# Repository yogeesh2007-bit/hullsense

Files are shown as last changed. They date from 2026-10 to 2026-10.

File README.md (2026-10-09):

# HULLSENSE

**Real-time strike localisation and breach sizing for crewed-module walls.**
SEDHACKS '26 · Track 03 Space Instrumentation · Hardware
Team **BYTEMELATER** · Team lead **Yogeeshwaran C** · Rajalakshmi Engineering College, Chennai

When debris hits a space-station wall, the crew needs three answers fast: *where did it hit, did it breach, and how long do we have?* Today those answers can take days. On the ISS in 2020 a leak was finally found with floating tea leaves. HULLSENSE answers all three in seconds with five ₹20 piezo discs, one pressure sensor and an ESP32, for about ₹1,479.

- 📄 **Build brief and documentation:** https://yogeesh2007-bit.github.io/hullsense/
- 🖥️ **Live dashboard** (simulation mode works without hardware): https://yogeesh2007-bit.github.io/hullsense/dashboard/
- 🔧 **Firmware:** [`firmware/hullsense_node`](firmware/hullsense_node)
- 📐 **CAD model:** [`hardware/cad`](hardware/cad) (STEP assembly, STL parts, dimensioned drawing); interactive viewer at `docs/cad/`

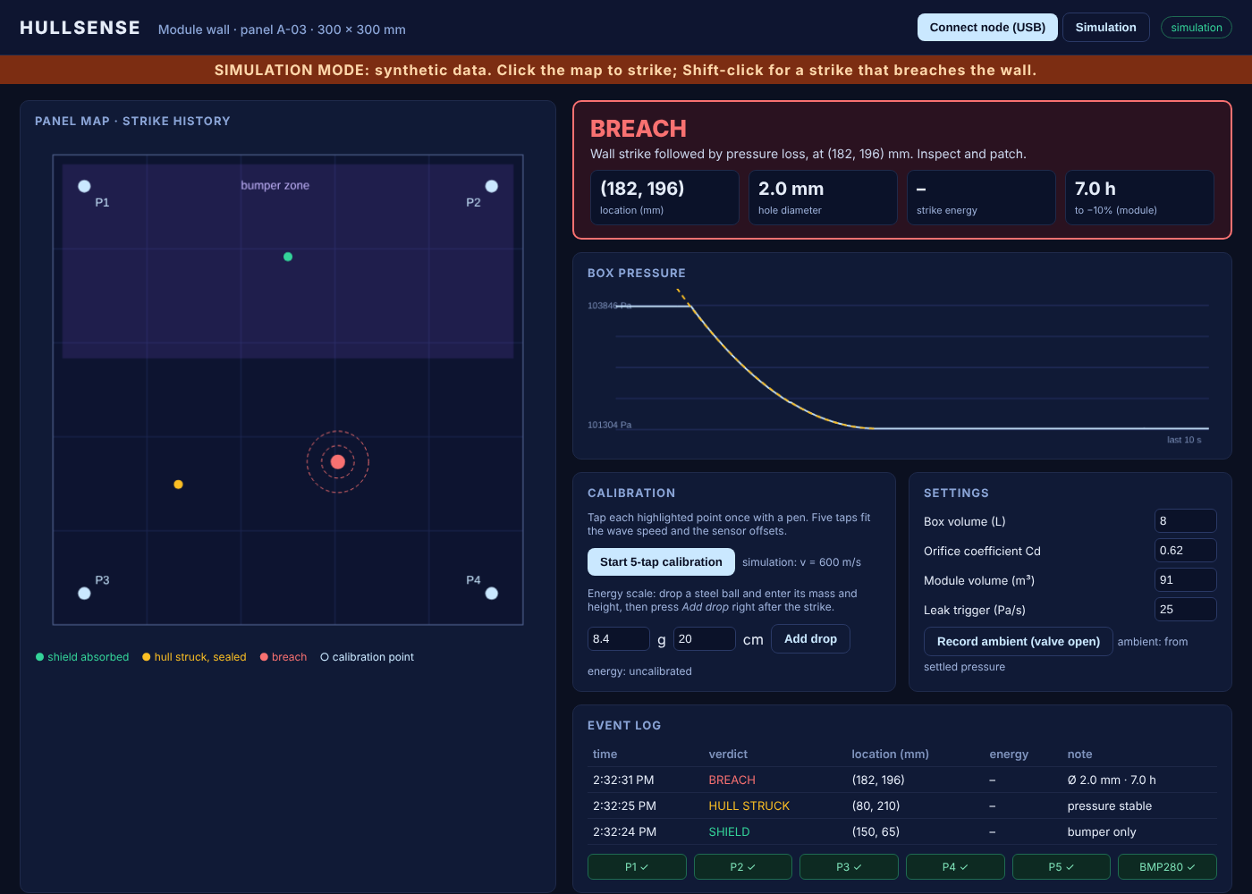
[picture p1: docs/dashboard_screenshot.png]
Dashboard in simulation mode


## How it works

| Step | What happens | Where |
|---|---|---|
| 1 · Strike | A strike sends a ripple through the 1 mm aluminium wall. | test rig |
| 2 · Timing | Four corner piezos and one bumper piezo feed band-pass filters and LM339 comparators; the ESP32's MCPWM capture hardware timestamps every edge at 12.5 ns. | `firmware/` |
| 3 · Locate | The dashboard finds the point that best explains the four arrival times (least squares, after a 5-tap calibration of wave speed and sensor offsets). | `docs/dashboard/solver.js` |
| 4 · Triage | Bumper sensor first → **shield absorbed**. Wall strike with steady pressure → **hull struck, sealed**. | `solver.js · triage()` |
| 5 · Size | If box pressure falls after a wall strike, the decay curve is fitted with the orifice equation to get the hole diameter, then scaled to a station-class module with a choked-flow model → **breach: location, Ø, minutes left**. | `solver.js · fitBreach(), flightMinutes()` |

## Repository layout

```
firmware/hullsense_node/   ESP32 firmware (Arduino-ESP32 3.x)
docs/                      GitHub Pages site: build brief + live dashboard
docs/dashboard/            Web Serial dashboard (index.html, app.js, solver.js)
hardware/                  BOM, wiring, one-channel schematic
hardware/cad/              Parametric CadQuery model: STEP, GLB, STL, A3 drawing, renders
analysis/                  Python model: decay curves, hole sizing, flight scaling
tests/                     Solver tests on simulated strikes (node tests/solver.test.js)
```

## Hardware

See [`hardware/BOM.csv`](hardware/BOM.csv) and [`hardware/wiring.md`](hardware/wiring.md).

| Signal | ESP32 pin |
|---|---|
| P1 wall (20, 20) mm | GPIO 34 |
| P2 wall (280, 20) mm | GPIO 35 |
| P3 wall (20, 280) mm | GPIO 32 |
| P4 wall (280, 280) mm | GPIO 33 |
| P5 bumper | GPIO 25 |
| Timer sync (internal loop-back, leave unconnected) | GPIO 26 |
| BMP280 SDA / SCL | GPIO 21 / 22 |

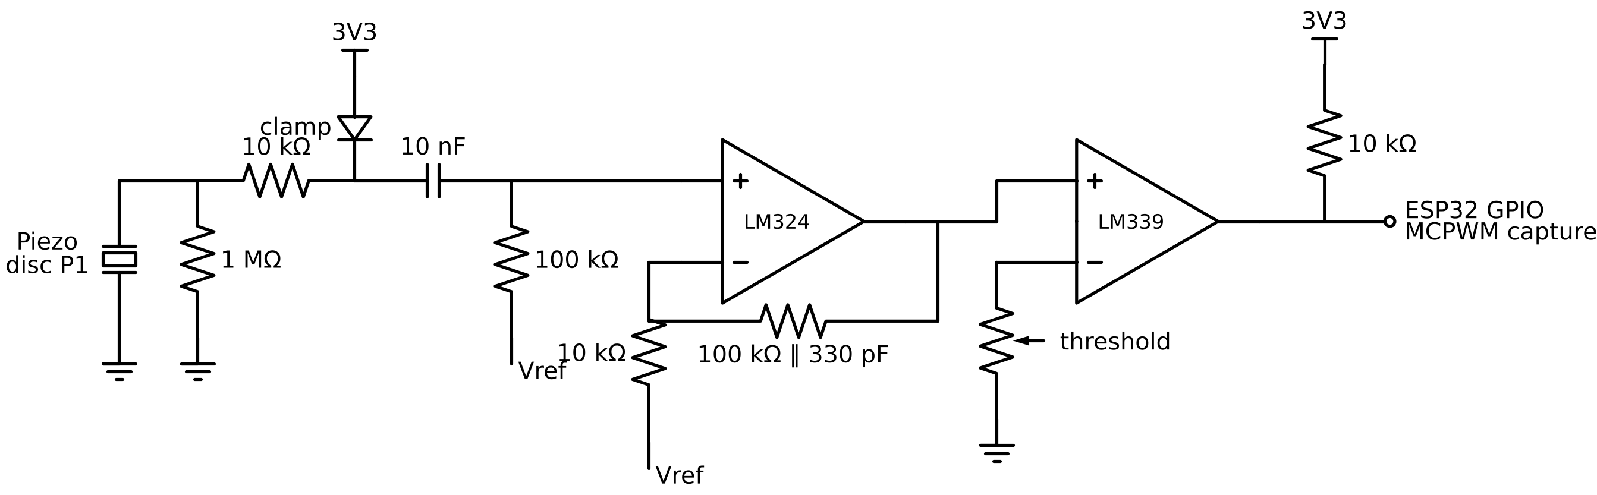
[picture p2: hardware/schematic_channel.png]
One channel


## CAD model

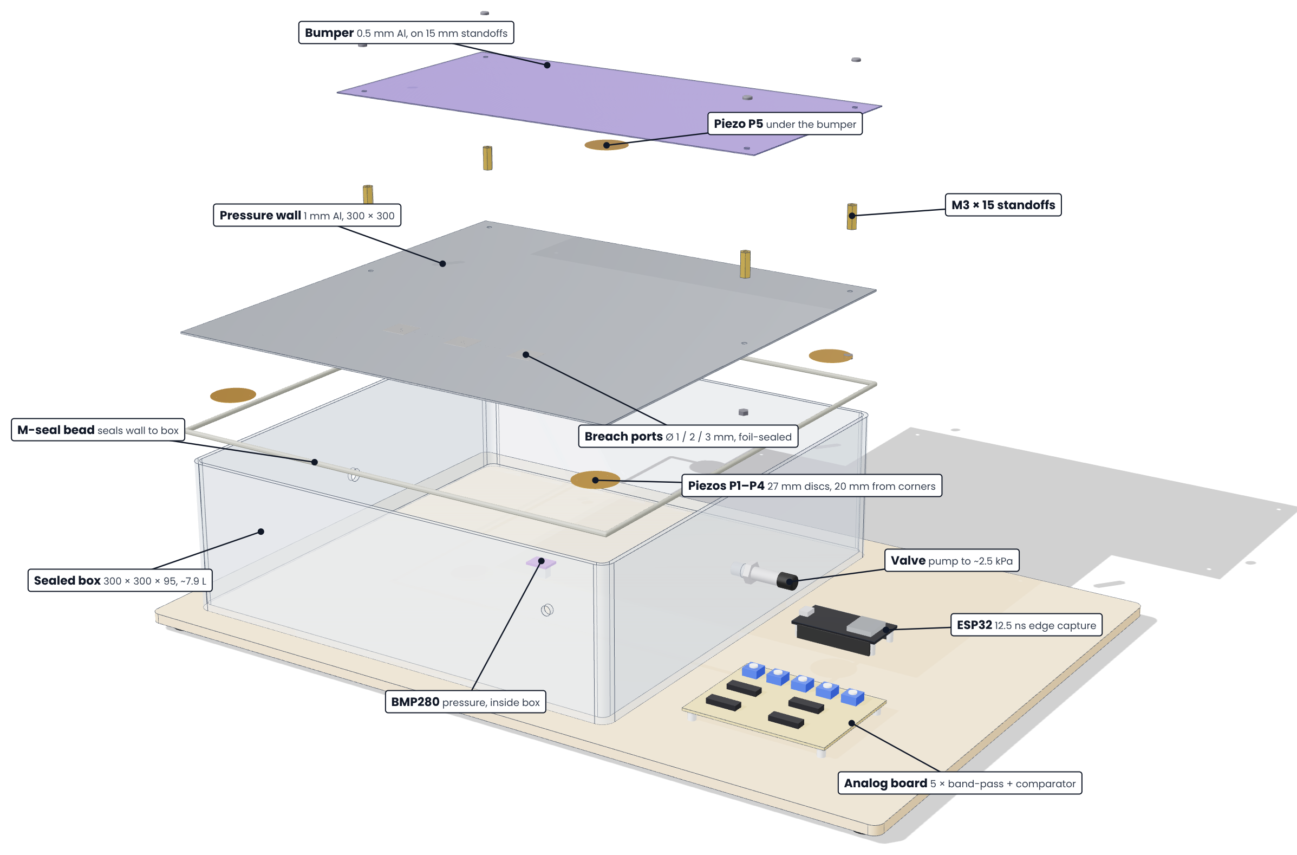
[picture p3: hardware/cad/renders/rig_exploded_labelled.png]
Exploded CAD view


`hardware/cad/hullsense_rig.py` is a parametric CadQuery model of the whole rig. Every dimension lives at the top of the file, and the sensor positions match `solver.js`. Run `pip install cadquery && python3 hardware/cad/hullsense_rig.py && python3 hardware/cad/drawing.py` to regenerate:

| File | What it is |
|---|---|
| `hullsense_rig.step` | Coloured assembly for Fusion 360, SolidWorks, FreeCAD or Onshape |
| `hullsense_rig.glb`, `hullsense_rig_exploded.glb` | Web and Blender versions (used by the viewer in `docs/cad/`) |
| `stl/*.stl` | Wall plate, bumper, box, standoff and base board as separate parts |
| `hullsense_rig_drawing.pdf` | A3 workshop drawing: wall layout, section A–A and parts list |

## Build and flash the firmware

1. Arduino IDE 2.x → Boards Manager → install **esp32 by Espressif, version 3.x** (tested with 3.0.7).
2. Library Manager → install **Adafruit BMP280 Library**.
3. Open `firmware/hullsense_node/hullsense_node.ino`, board **ESP32 Dev Module**, upload.
4. Serial output is JSON lines at 921600 baud (`evt`, `p`, `hb`).

Build check: compiles for ESP32 Dev Module with Arduino-ESP32 3.0.7, using 317 KB flash (24%) and 21 KB RAM (6%).

## Run the dashboard

Open https://yogeesh2007-bit.github.io/hullsense/dashboard/ in Chrome or Edge.

- **With the node:** *Connect node (USB)* → *Start 5-tap calibration* → tap the five highlighted points → strike the panel.
- **Without hardware:** *Simulation* → click the map to strike, Shift-click for a strike that breaches the wall.

## Tests

```
node tests/solver.test.js
python3 analysis/hullsense_model.py
```

The solver test recovers wave speed and sensor offsets from 5 simulated taps, locates 25 simulated strikes, and sizes simulated 1, 2 and 3 mm breaches. These are simulations; bench numbers from the real rig go in `analysis/results.md` once measured.

## Status and honest limits

- Lab strikes (dropped balls, punches), not 7 km/s hypervelocity impacts. The demo proves the locate → triage → size pipeline.
- Location accuracy target: median ≤ 2.5 cm on a 25-point grid. Hole-size target: within ±15%. Both are targets until the bench tests are logged.
- Prices for the ESP32, piezo and BMP280 were checked online in October 2026; the rest are estimates.

## Licence

MIT. NASA photographs used in the documentation are public domain.

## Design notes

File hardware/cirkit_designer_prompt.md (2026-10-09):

# Cirkit Designer prompt: HULLSENSE sensor node

Paste the block below into Cirkit Designer's AI prompt. It matches `hardware/wiring.md` and the firmware pin map in `firmware/hullsense_node/config.h`.

```
Design the full wiring diagram for "HULLSENSE", an ESP32 impact-localisation and pressure-monitoring node. Use these exact parts, nets and pins.

PARTS
- 1x ESP32 DevKit V1 (30-pin, ESP-WROOM-32), powered from USB
- 5x piezo disc 27 mm (2-wire): P1, P2, P3, P4 (on the wall) and P5 (on the bumper)
- 2x LM324 quad op-amp (U1, U2), DIP-14
- 2x LM339 quad comparator (U3, U4), DIP-14
- 1x BMP280 pressure sensor module (GY-BMP280, I2C)
- 5x 10 kΩ trimpot (RV1-RV5) for the comparator thresholds
- Per channel (x5): 1 MΩ, 10 kΩ, 100 kΩ, 100 kΩ, 10 kΩ, 10 kΩ resistors; 10 nF and 330 pF capacitors; 2x 1N4148 diodes
- Reference: 2x 10 kΩ divider + 10 µF capacitor
- Decoupling: 4x 100 nF (one per IC)

POWER NETS
- 5V net = ESP32 VIN pin (5 V from USB). It powers U1-U4: LM324 pin 4 = VCC, pin 11 = GND; LM339 pin 3 = VCC, pin 12 = GND.
- 3V3 net = ESP32 3V3 pin. It powers the BMP280, the comparator pull-ups, the clamp diodes and the trimpots.
- VREF net = 1.65 V: a 10 kΩ from 3V3 to VREF, a 10 kΩ from VREF to GND, and 10 µF from VREF to GND.
- All grounds are common.

ONE ANALOG CHANNEL (draw 5 identical copies, CH1-CH5)
1. Piezo (+) goes to node IN; piezo (-) to GND. Add 1 MΩ from IN to GND (bleed).
2. 10 kΩ series resistor from IN to node CLAMP. Add a 1N4148 from CLAMP to 3V3 (cathode at 3V3) and a 1N4148 from GND to CLAMP (cathode at CLAMP).
3. A 10 nF coupling capacitor from CLAMP to node B. Add 100 kΩ from node B to VREF.
4. Op-amp, non-inverting amplifier with gain about 11: (+) input = node B. Feedback from the output to the (-) input is 100 kΩ in parallel with 330 pF. Add 10 kΩ from the (-) input to VREF.
5. Comparator: (+) input = op-amp output. (-) input = trimpot wiper (trimpot ends to 3V3 and GND).
6. The comparator output is open-collector: add a 10 kΩ pull-up to 3V3 (NOT 5V). This node is the channel output to the ESP32.

CHANNEL ALLOCATION
- Op-amps: U1A -> CH1, U1B -> CH2, U1C -> CH3, U1D -> CH4, U2A -> CH5. On the unused U2B-U2D, tie (+) to VREF and the output to (-).
- Comparators: U3A -> CH1, U3B -> CH2, U3C -> CH3, U3D -> CH4, U4A -> CH5. On the unused U4B-U4D, tie both inputs to GND.

ESP32 CONNECTIONS
- CH1 (P1, wall corner 20,20 mm) -> GPIO34
- CH2 (P2, wall corner 280,20 mm) -> GPIO35
- CH3 (P3, wall corner 20,280 mm) -> GPIO32
- CH4 (P4, wall corner 280,280 mm) -> GPIO33
- CH5 (P5, bumper) -> GPIO25
- GPIO26 = timer sync loop-back used inside the firmware: leave it unconnected.
- BMP280: VCC -> 3V3, GND -> GND, SCL -> GPIO22, SDA -> GPIO21, CSB -> 3V3 (selects I2C), SDO -> GND (address 0x76).

LAYOUT AND LABELS
- Place the ESP32 in the centre, the five channels in a column on the left, and the BMP280 on the right.
- Label every net: 5V, 3V3, VREF, GND, CH1_OUT ... CH5_OUT, SDA, SCL.
- Label each piezo P1-P5 and each trimpot "threshold CHn".
- Colour the wires: red 5V, orange 3V3, black GND, blue signals, green I2C.
```

## If the tool is missing a part

- **No LM339:** use LM393 (dual comparator, same open-collector output). You will need 3 chips for 5 channels.
- **No piezo disc:** use "piezo buzzer (passive)" or a generic 2-pin sensor, and label it "27 mm piezo disc".
- **Circuit too large for one prompt:** first ask for one channel plus the ESP32 and the BMP280, then say "duplicate the channel four more times to GPIO35, 32, 33 and 25".

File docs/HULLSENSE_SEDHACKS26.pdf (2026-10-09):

# SEDHACKS'26

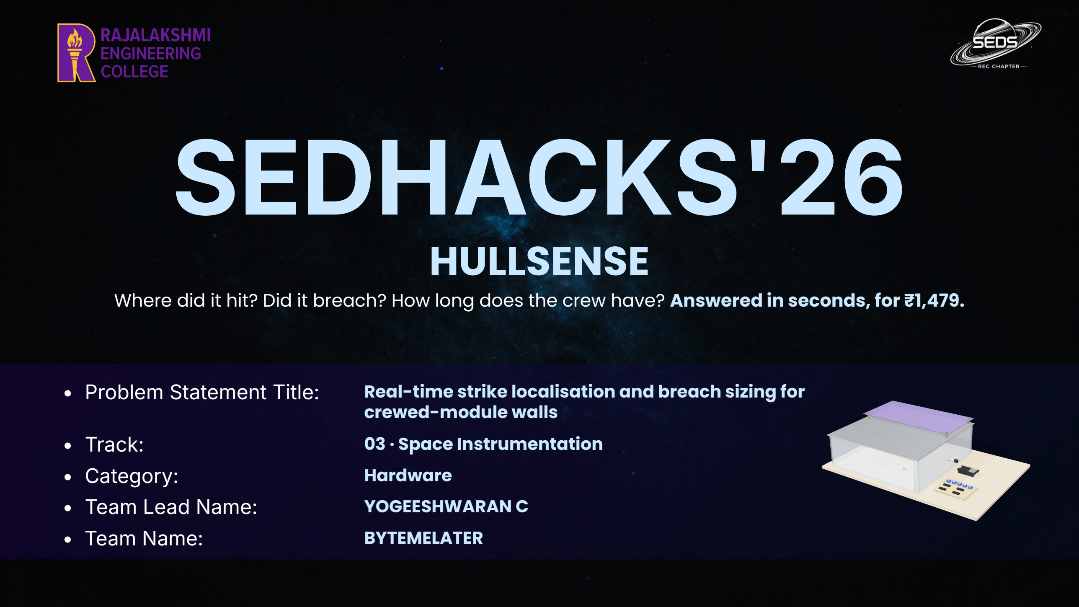
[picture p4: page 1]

## - Problem Statement Title:

## - Track:

## - Team Name:

## - Category: - Team Lead Name:

# Real-time strike localisation and breach sizing for crewed-module walls 03 · Space Instrumentation

# BYTEMELATER

# Hardware YOGEESHWARAN C

# HULLSENSE

Where did it hit? Did it breach? How long does the crew have? Answered in seconds, for ₹1,479.

# PROPOSED SOLUTION

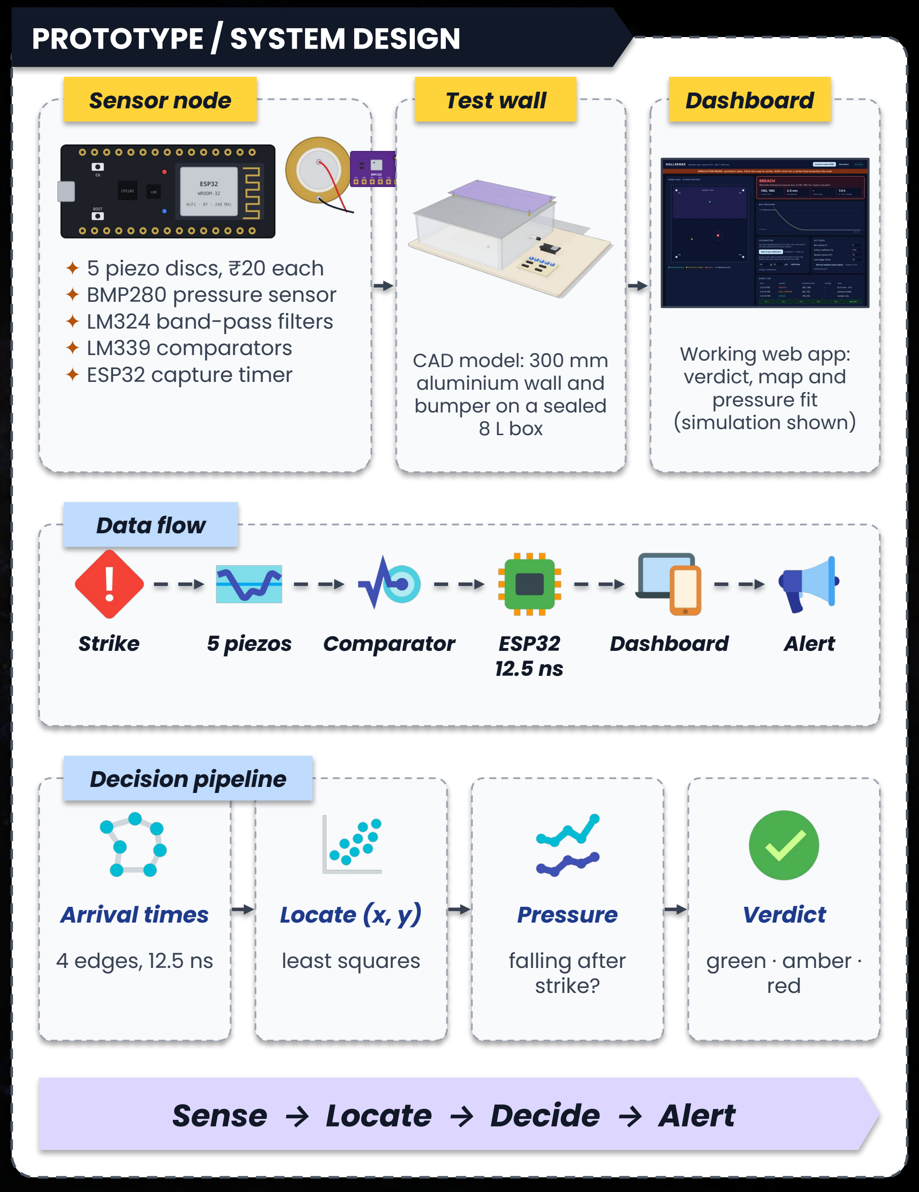
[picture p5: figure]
PROTOTYPE / SYSTEM DESIGN; Sensor node; ✦ 5 piezo discs, ₹20 each ✦ BMP280 pressure sensor ✦ LM324 band-pass filters ✦ LM339 comparators ✦ ESP32 capture timer; Test wall; CAD model: 300 mm aluminium wall and bumper on a sealed 8 L box; Dashboard; Working web app: verdict, map and pressure fit (simulation shown); Data flow; Strike; 5 piezos Comparator; ESP32; Alert; Arrival times 4 edges, 12.5 ns; Locate (x, y) least squares; Pressure falling after strike?; Verdict green · amber · red; Decision pipeline; Sense Locate Decide Alert →
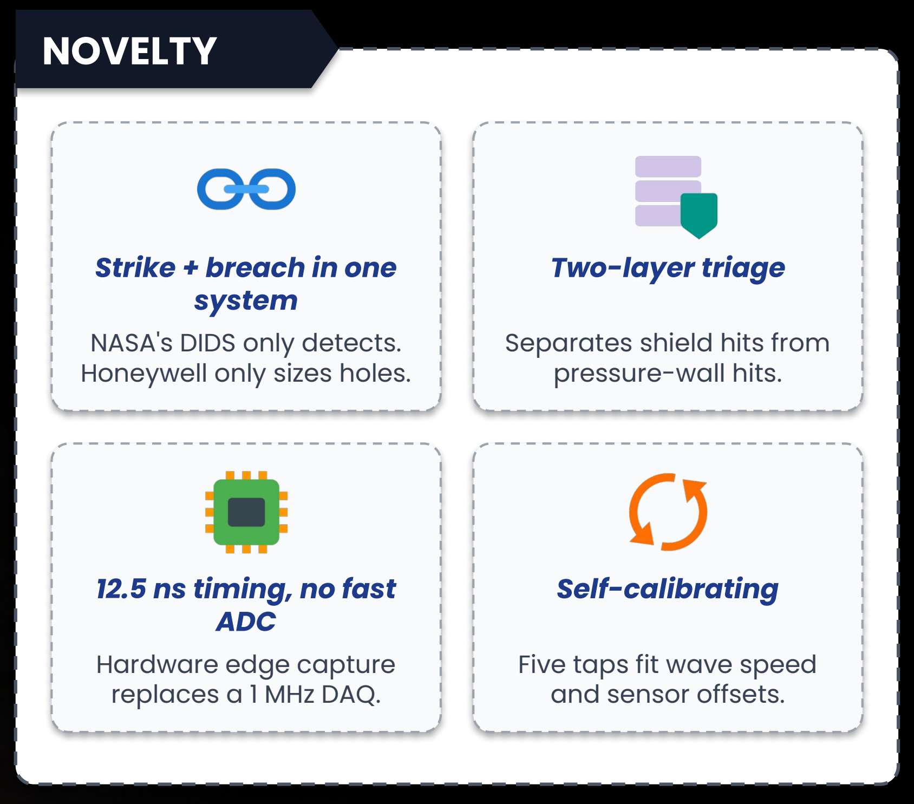
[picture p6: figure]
NOVELTY; Strike + breach in one system NASA's DIDS only detects. Honeywell only sizes holes.; Two-layer triage; Separates shield hits from pressure-wall hits.; 12.5 ns timing, no fast ADC Hardware edge capture replaces a 1 MHz DAQ.; Self-calibrating; Five taps fit wave speed and sensor offsets.

## THE SOLUTION

HULLSENSE is a ₹1,479 sensor skin for a crewed-module wall. When something strikes it, the system tells the crew where it hit, whether the hull was breached, how big the hole is and how long they have, within seconds.

### Locate the strike

Four corner sensors time the ripple a strike sends through the wall. The arrival-time differences give the (x, y) point.

### Shield vs hull

A fifth sensor on the outer bumper tells a harmless shield hit apart from a strike on the pressure wall.

### Size the breach

If box pressure falls after a wall strike, the decay curve gives the hole diameter and the minutes left.

### Alert in seconds

The dashboard shows the verdict, the location and the pressure fit as soon as the strike lands.

A real strike: micrometeoroid hole in ISS insulation (NASA, 2007)

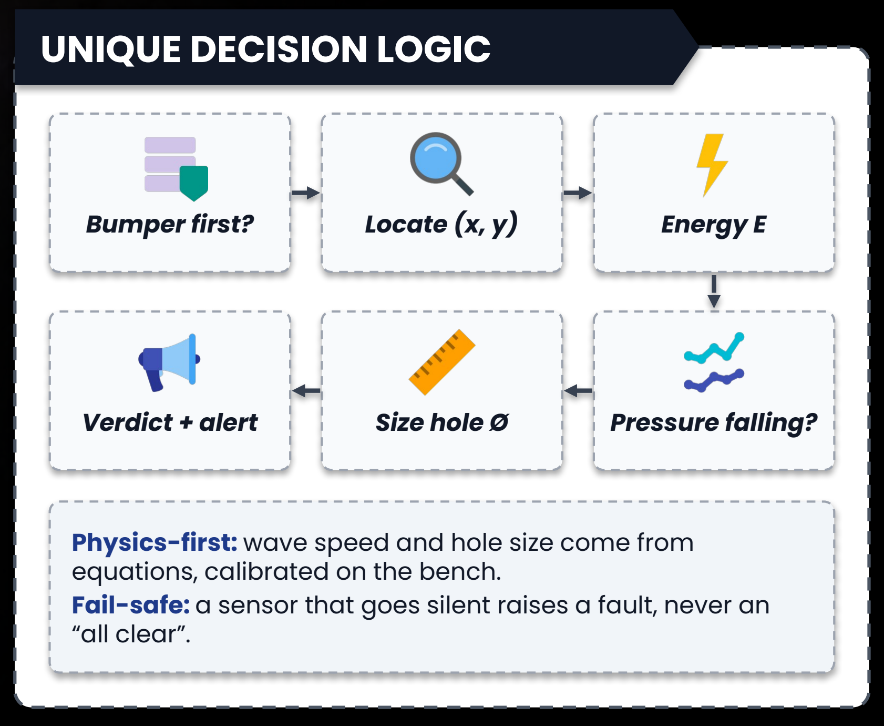
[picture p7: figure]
UNIQUE DECISION LOGIC; Bumper first?; Locate (x, y); Energy E; Verdict + alert; Size hole Ø; Pressure falling?; equations, calibrated on the bench.; “all clear”.

Physics-first: wave speed and hole size come from Fail-safe: a sensor that goes silent raises a fault, never an

# TECHNICAL APPROACH

## PHYSICS + SIGNAL

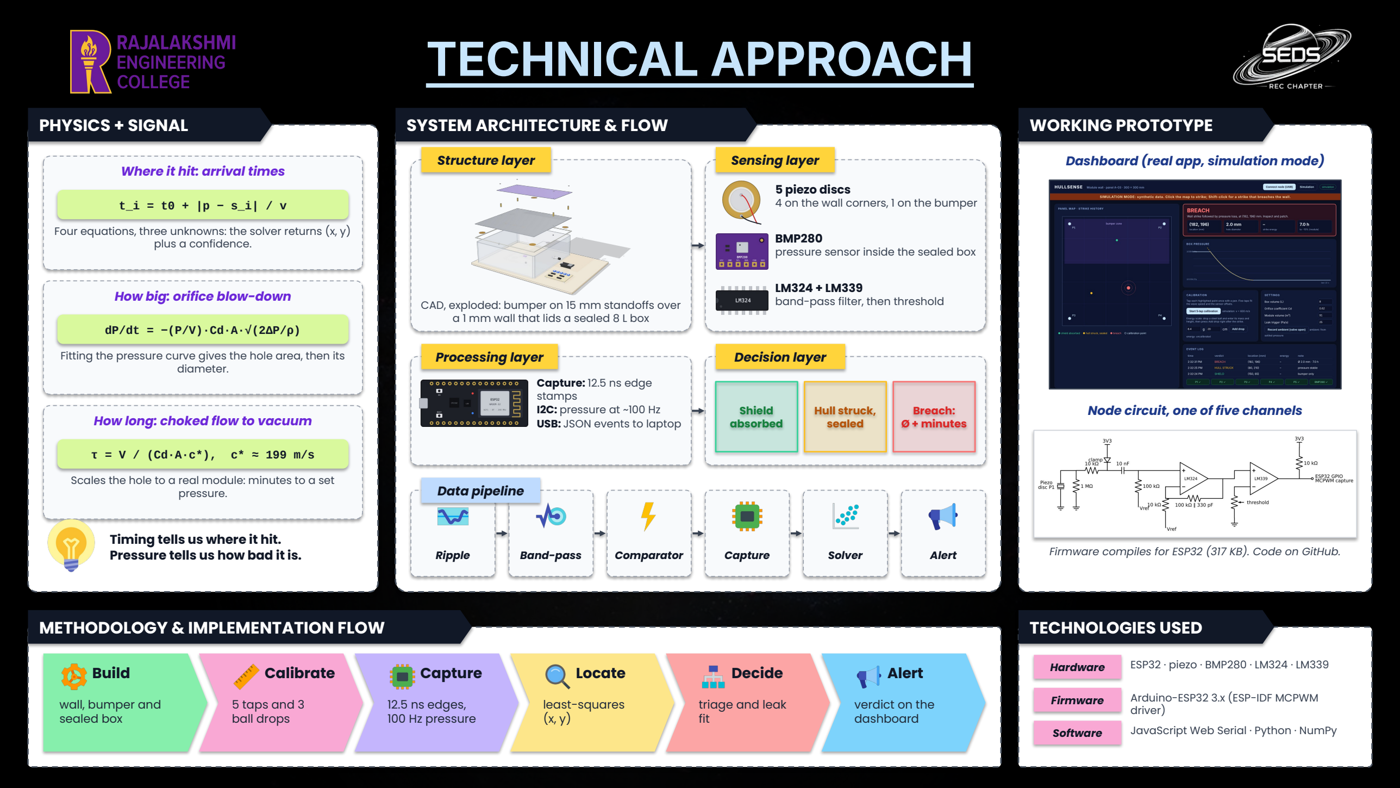
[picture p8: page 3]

Where it hit: arrival times

t_i = t0 + |p − s_i| / v
Four equations, three unknowns: the solver returns (x, y) plus a confidence.

How big: orifice blow-down

dP/dt = −(P/V)·Cd·A·√(2ΔP/ρ)
Fitting the pressure curve gives the hole area, then its diameter.

How long: choked flow to vacuum

τ = V / (Cd·A·c*), c* ≈ 199 m/s
Scales the hole to a real module: minutes to a set pressure.

Timing tells us where it hit. Pressure tells us how bad it is.

## SYSTEM ARCHITECTURE & FLOW

Structure layer

CAD, exploded: bumper on 15 mm standoffs over a 1 mm wall that lids a sealed 8 L box

Sensing layer

### 5 piezo discs

4 on the wall corners, 1 on the bumper BMP280
pressure sensor inside the sealed box LM324 + LM339
band-pass filter, then threshold

Processing layer
Capture: 12.5 ns edge
stamps
I2C: pressure at ~100 Hz
USB: JSON events to laptop

Decision layer

Shield
absorbed

Hull struck,
sealed

Breach:
Ø + minutes
Ripple | Band-pass | Comparator | Capture | Solver | Alert

Data pipeline

## WORKING PROTOTYPE

Dashboard (real app, simulation mode)

Node circuit, one of five channels

Firmware compiles for ESP32 (317 KB). Code on GitHub.

## METHODOLOGY & IMPLEMENTATION FLOW

### Build

wall, bumper and
sealed box

### Calibrate

5 taps and 3
ball drops

### Capture

12.5 ns edges,
100 Hz pressure

### Locate

least-squares
(x, y)

### Decide

triage and leak
fit

### Alert

verdict on the
dashboard

## TECHNOLOGIES USED

Hardware | ESP32 · piezo · BMP280 · LM324 · LM339
Firmware | Arduino-ESP32 3.x (ESP-IDF MCPWM driver)
Software | JavaScript Web Serial · Python · NumPy

# FEASIBILITY & VIABILITY

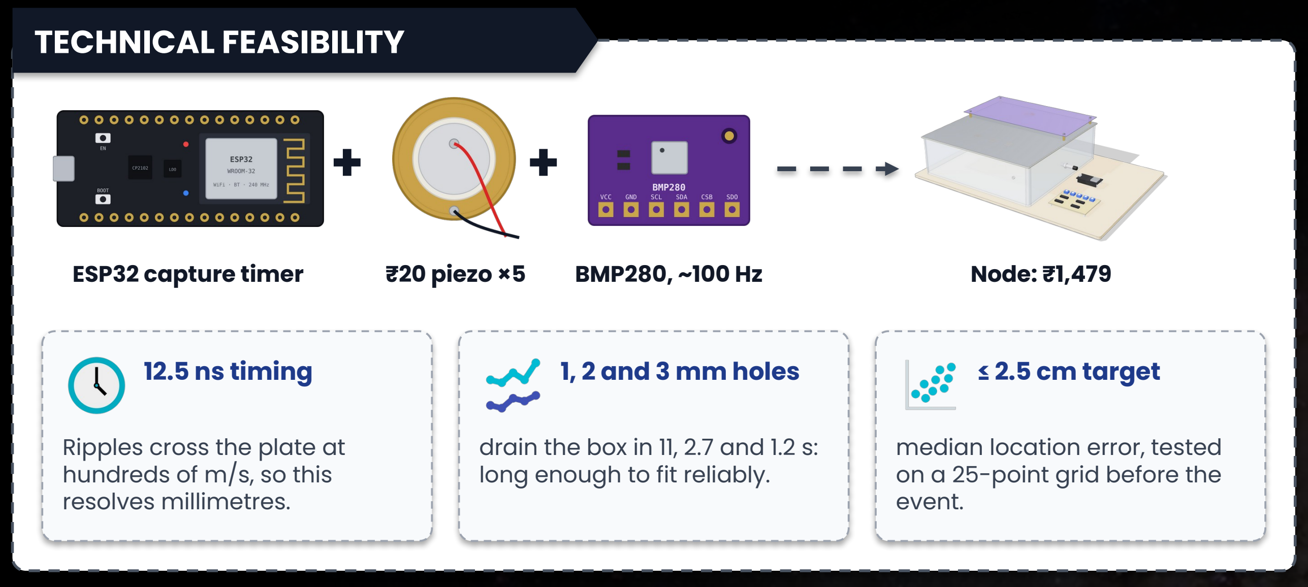
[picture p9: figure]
TECHNICAL FEASIBILITY; ESP32 capture timer; ₹20 piezo ×5; BMP280, ~100 Hz; Node: ₹1,479; 12.5 ns timing; Ripples cross the plate at hundreds of m/s, so this resolves millimetres.; 1, 2 and 3 mm holes; drain the box in 11, 2.7 and 1.2 s: long enough to fit reliably.; ≤ 2.5 cm target; median location error, tested on a 25-point grid before the event.
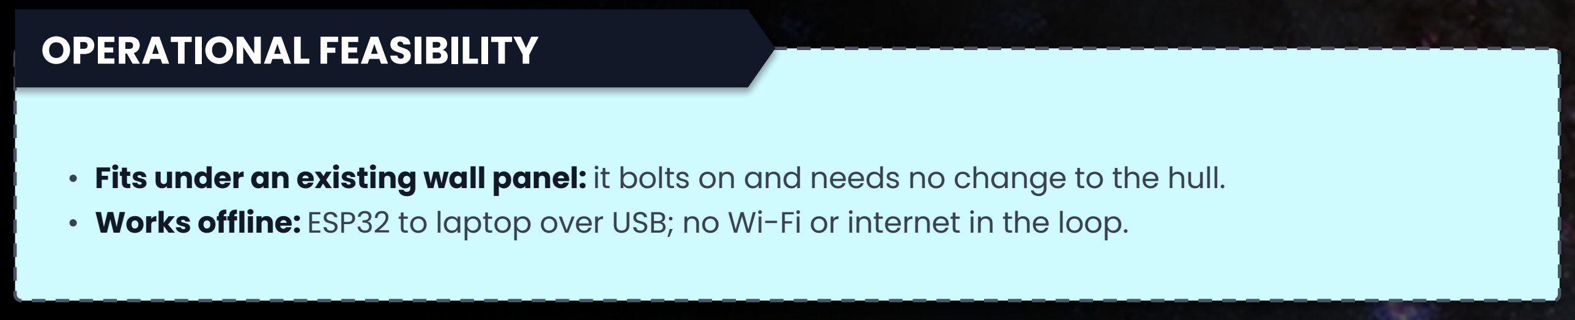
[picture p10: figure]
OPERATIONAL FEASIBILITY
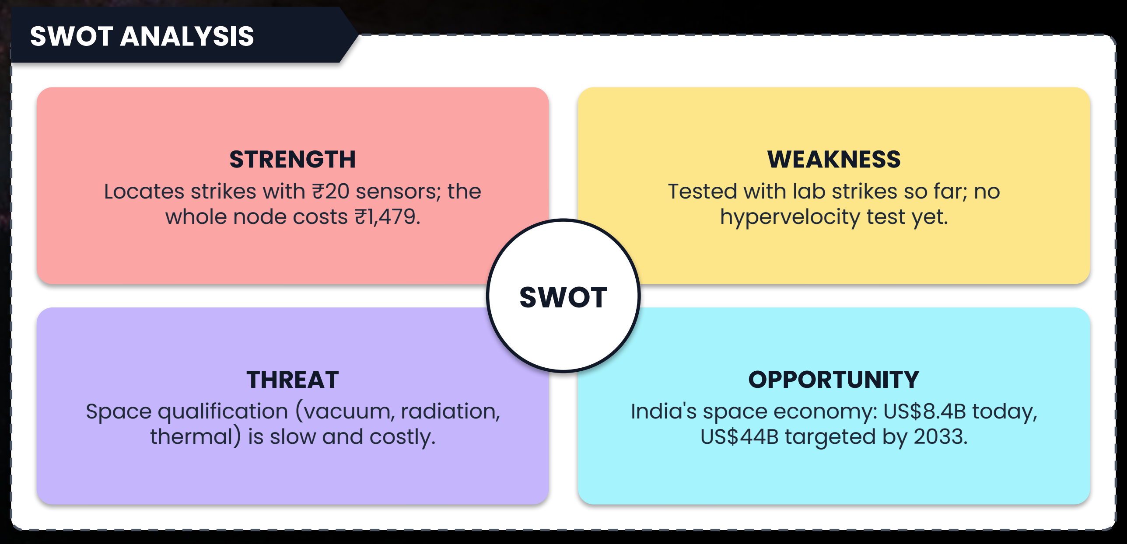
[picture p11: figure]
SWOT ANALYSIS; STRENGTH Locates strikes with ₹20 sensors; the whole node costs ₹1,479.; WEAKNESS Tested with lab strikes so far; no hypervelocity test yet.; THREAT Space qualification (vacuum, radiation, thermal) is slow and costly.; OPPORTUNITY India's space economy: US$8.4B today, US$44B targeted by 2033.; SWOT

- Fits under an existing wall panel: it bolts on and needs no change to the hull.
- Works offline: ESP32 to laptop over USB; no Wi-Fi or internet in the loop.

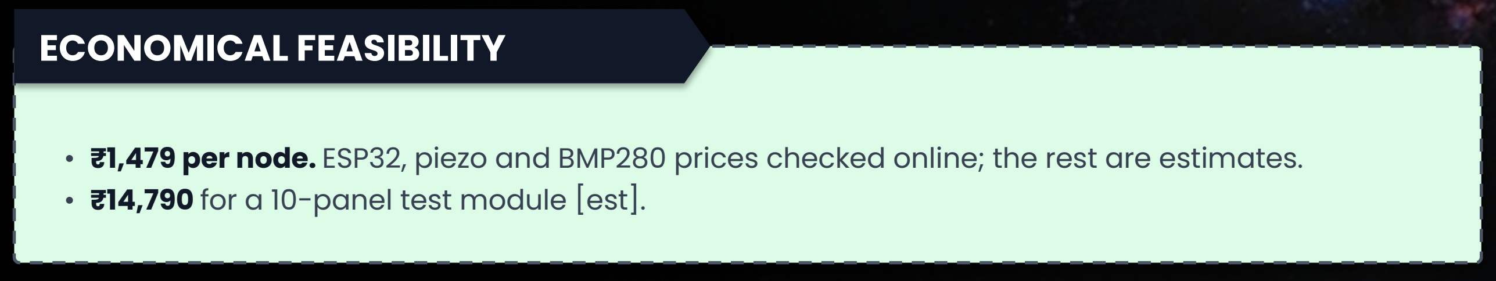
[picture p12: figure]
ECONOMICAL FEASIBILITY

- ₹1,479 per node. ESP32, piezo and BMP280 prices checked online; the rest are estimates.
- ₹14,790 for a 10-panel test module [est].

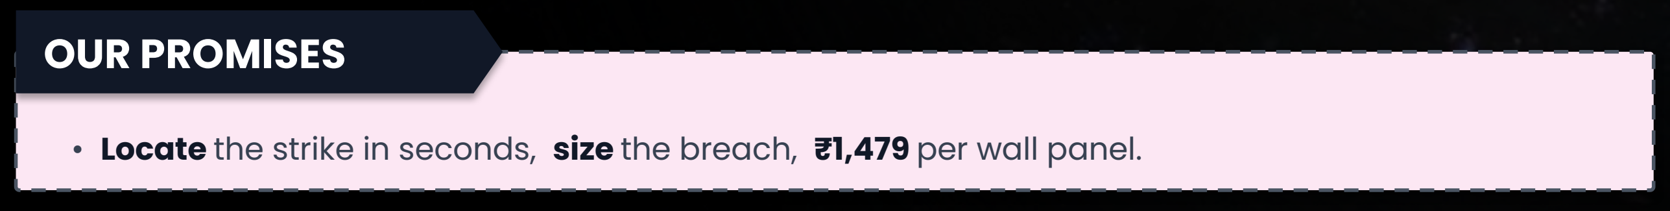
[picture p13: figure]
OUR PROMISES

- Locate the strike in seconds, size the breach, ₹1,479 per wall panel.

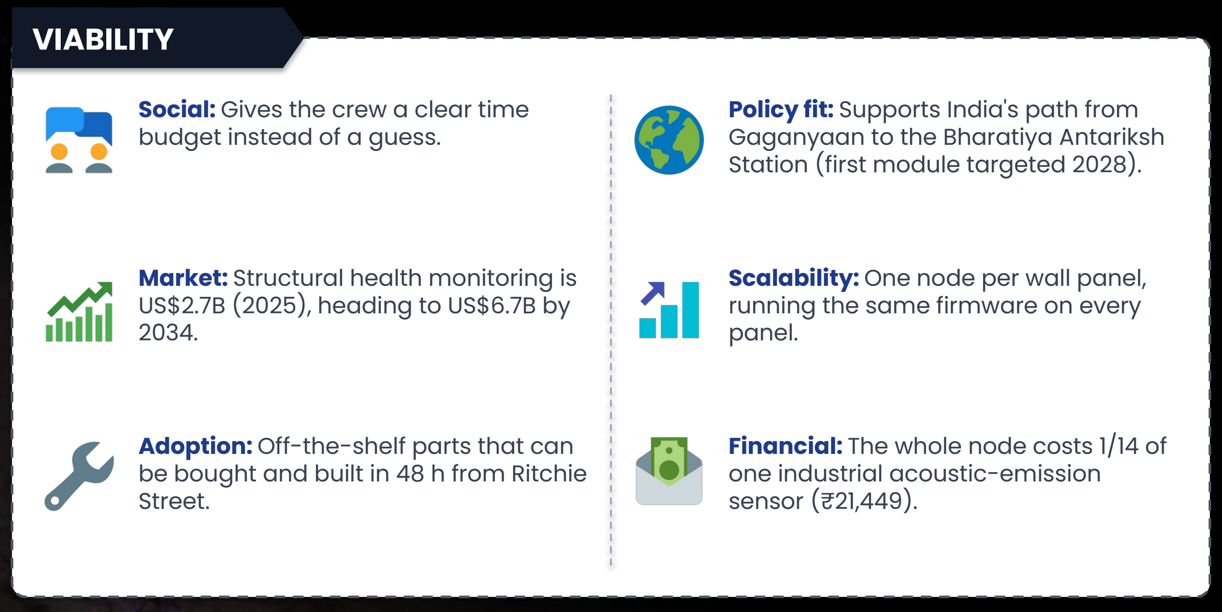
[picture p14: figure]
VIABILITY; Social: Gives the crew a clear time budget instead of a guess.; Policy fit: Supports India's path from Gaganyaan to the Bharatiya Antariksh Station (first module targeted 2028).; Market: Structural health monitoring is US$2.7B (2025), heading to US$6.7B by 2034.; Scalability: One node per wall panel, running the same firmware on every panel.; Adoption: Off-the-shelf parts that can Street.; Financial: The whole node costs 1/14 of one industrial acoustic-emission sensor (₹21,449).

be bought and built in 48 h from Ritchie

# IMPACT & BENEFITS

## IMPACT AT A GLANCE

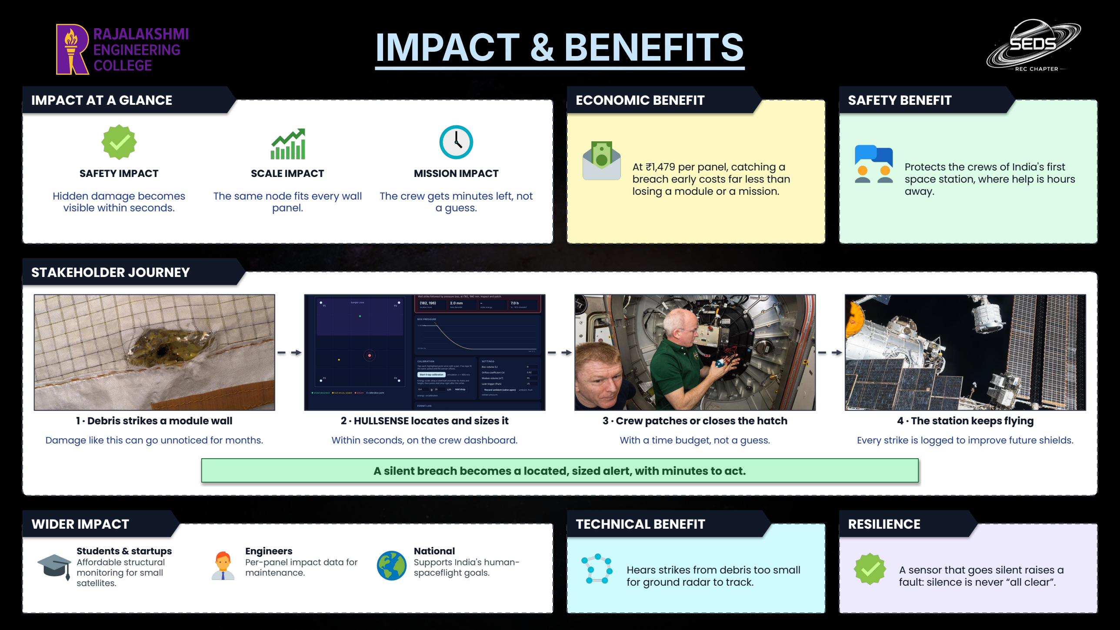
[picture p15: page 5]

SAFETY IMPACT
Hidden damage becomes
visible within seconds.

SCALE IMPACT
The same node fits every wall panel.

MISSION IMPACT
The crew gets minutes left, not a guess.

## ECONOMIC BENEFIT

At ₹1,479 per panel, catching a breach early costs far less than losing a module or a mission.

## SAFETY BENEFIT

Protects the crews of India's first space station, where help is hours away.

## STAKEHOLDER JOURNEY

1 · Debris strikes a module wall
Damage like this can go unnoticed for months.

2 · HULLSENSE locates and sizes it
Within seconds, on the crew dashboard.

3 · Crew patches or closes the hatch
With a time budget, not a guess.

4 · The station keeps flying
Every strike is logged to improve future shields.

## WIDER IMPACT

Students & startups
Affordable structural
monitoring for small
satellites.

Engineers
Per-panel impact data for
maintenance.

National
Supports India's human-spaceflight goals.

## TECHNICAL BENEFIT

Hears strikes from debris too small for ground radar to track.

## RESILIENCE

A sensor that goes silent raises a fault: silence is never “all clear”.

A silent breach becomes a located, sized alert, with minutes to act.

# RESEARCH & REFERENCE

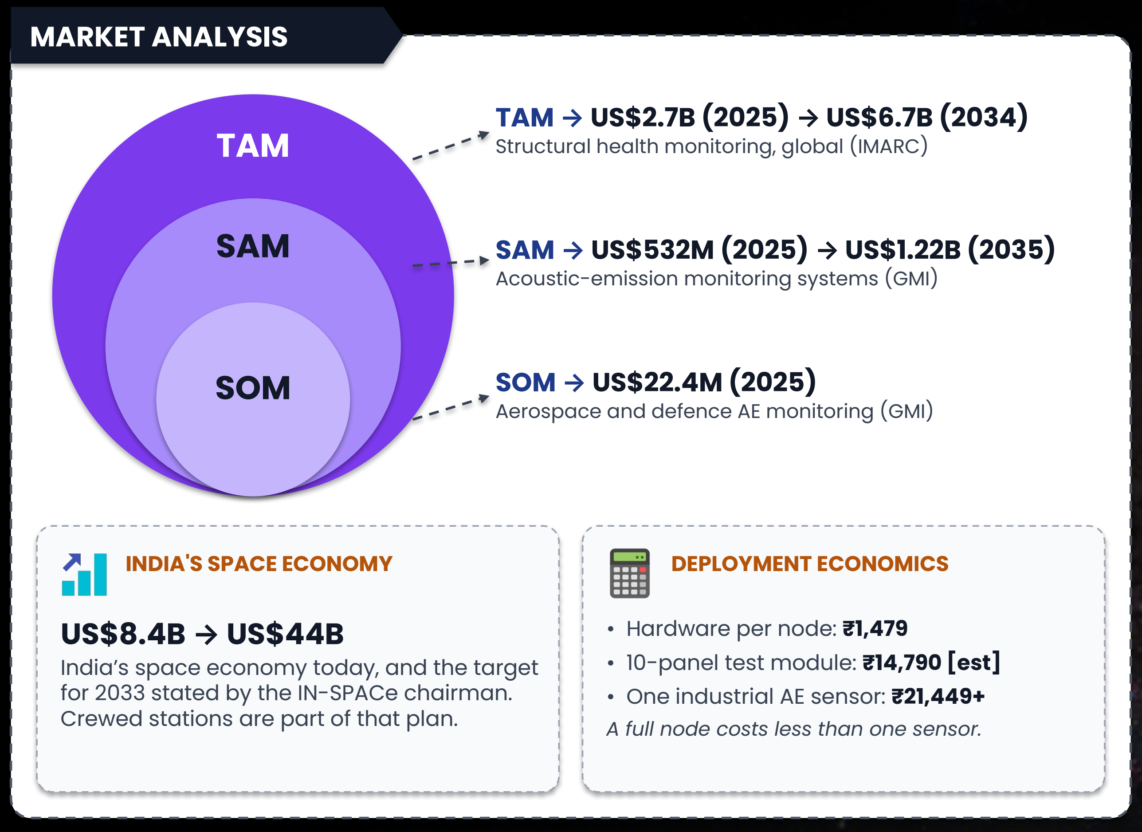
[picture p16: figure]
MARKET ANALYSIS; TAM; SAM; SOM; TAM → US$2.7B (2025) US$6.7B (2034) → Structural health monitoring, global (IMARC); SAM → US$532M (2025) US$1.22B (2035) → Acoustic-emission monitoring systems (GMI); SOM → US$22.4M (2025); INDIA'S SPACE ECONOMY US$8.4B US$44B →; Crewed stations are part of that plan.; DEPLOYMENT ECONOMICS; • Hardware per node: ₹1,479 • 10-panel test module: ₹14,790 [est] • One industrial AE sensor: ₹21,449+ A full node costs less than one sensor.

Aerospace and defence AE monitoring (GMI)

India’s space economy today, and the target for 2033 stated by the IN-SPACe chairman.

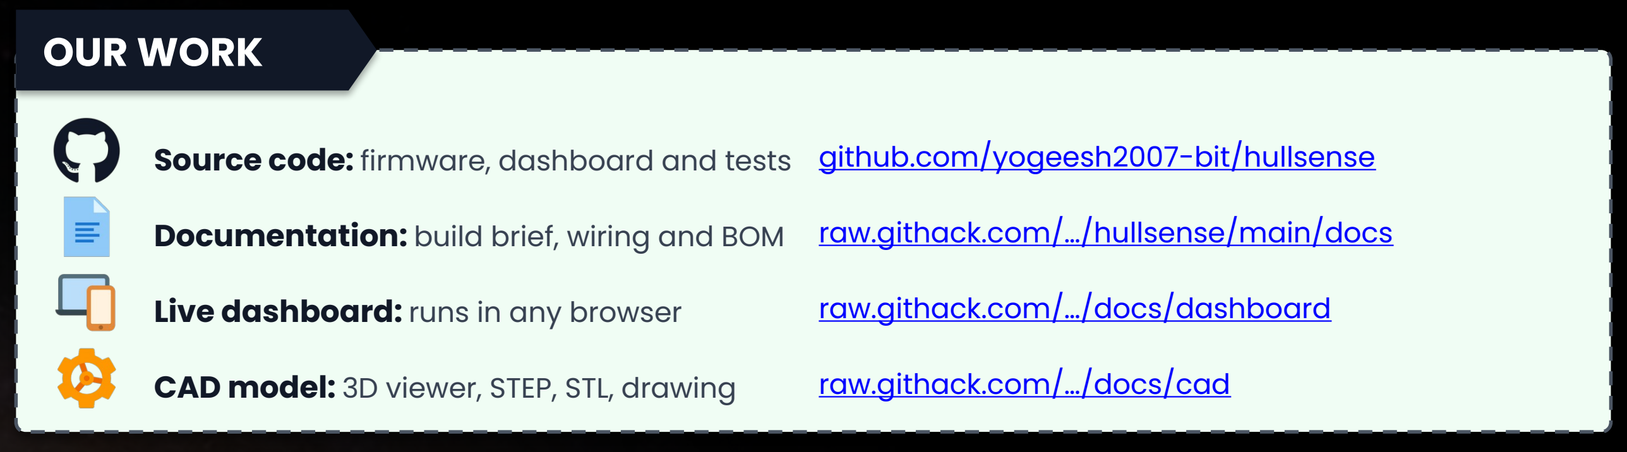
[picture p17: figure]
OUR WORK

Source code: firmware, dashboard and tests github.com/yogeesh2007-bit/hullsense Documentation: build brief, wiring and BOM raw.githack.com/…/hullsense/main/docs (https://raw.githack.com/yogeesh2007-bit/hullsense/main/docs/index.html)
Live dashboard: runs in any browser | raw.githack.com/…/docs/dashboard (https://raw.githack.com/yogeesh2007-bit/hullsense/main/docs/dashboard/index.html)
CAD model: 3D viewer, STEP, STL, drawing | raw.githack.com/…/docs/cad (https://raw.githack.com/yogeesh2007-bit/hullsense/main/docs/cad/index.html)

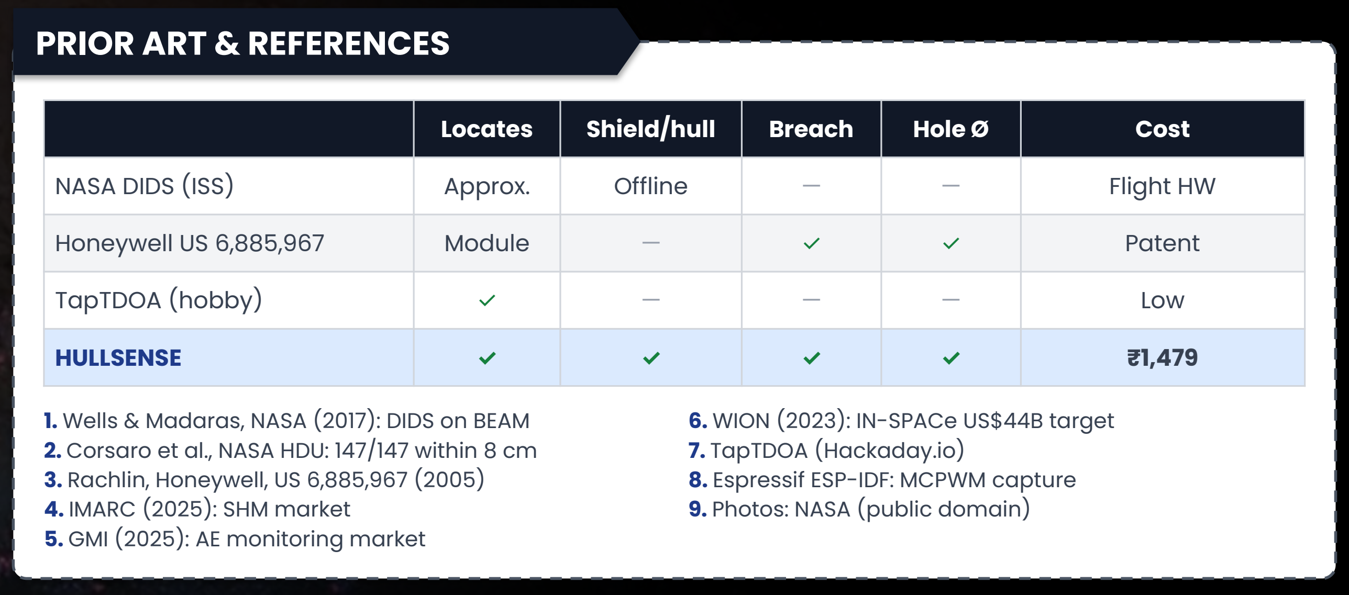
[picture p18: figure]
PRIOR ART & REFERENCES; Locates; Shield/hull; Breach; Hole Ø; Cost; NASA DIDS (ISS); Approx.; Offline; Flight HW; Honeywell US 6,885,967; Module; Patent; TapTDOA (hobby); Low; HULLSENSE; 4. IMARC (2025): SHM market 5. GMI (2025): AE monitoring market; 6. WION (2023): IN-SPACe US$44B target 7. TapTDOA (Hackaday.io) 8. Espressif ESP-IDF: MCPWM capture 9. Photos: NASA (public domain)

### 1. Wells & Madaras, NASA (2017): DIDS on BEAM 2. Corsaro et al., NASA HDU: 147/147 within 8 cm 3. Rachlin, Honeywell, US 6,885,967 (2005)

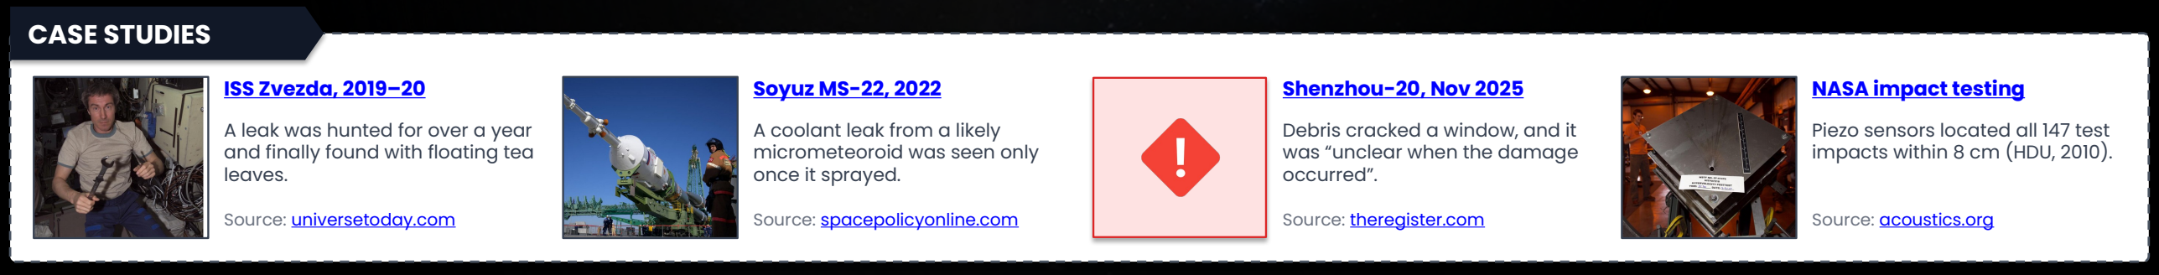
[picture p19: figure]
CASE STUDIES; ISS Zvezda, 2019–20 A leak was hunted for over a year and finally found with floating tea leaves.; Source: universetoday.com; Soyuz MS-22, 2022 A coolant leak from a likely micrometeoroid was seen only once it sprayed.; Source: spacepolicyonline.com; Shenzhou-20, Nov 2025 Debris cracked a window, and it was “unclear when the damage occurred”.; Source: theregister.com; NASA impact testing Piezo sensors located all 147 test impacts within 8 cm (HDU, 2010).; Source: acoustics.org

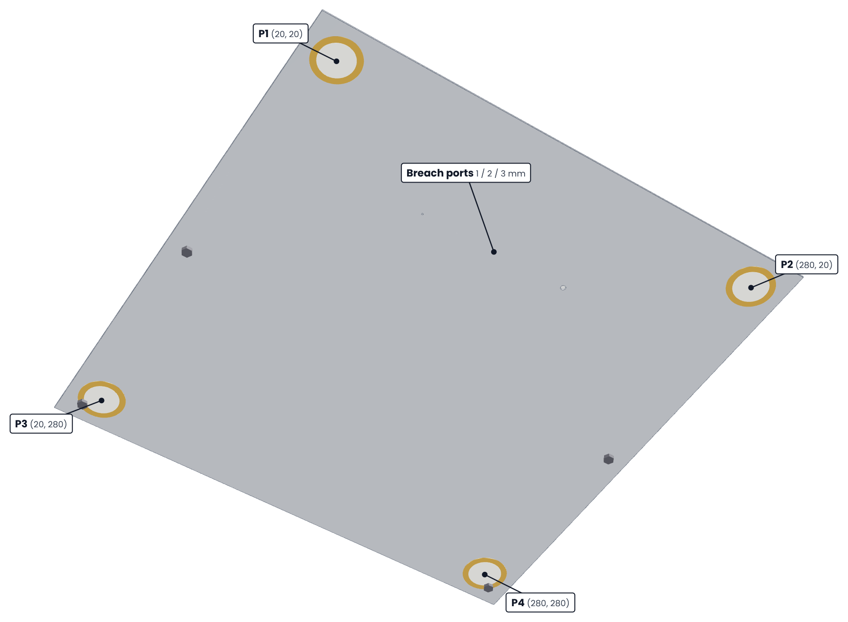
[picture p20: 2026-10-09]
hardware/cad/renders/wall_underside_sensors.png

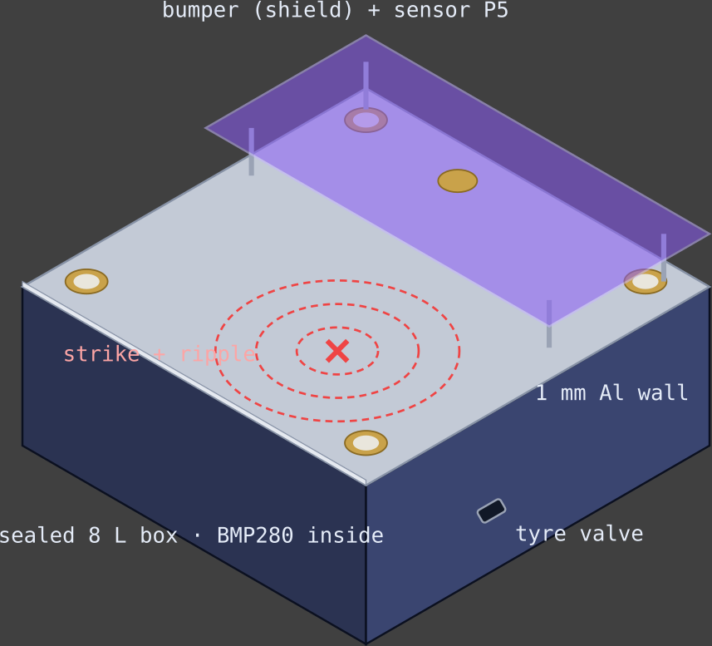
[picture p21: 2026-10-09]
hardware/rig_isometric.png

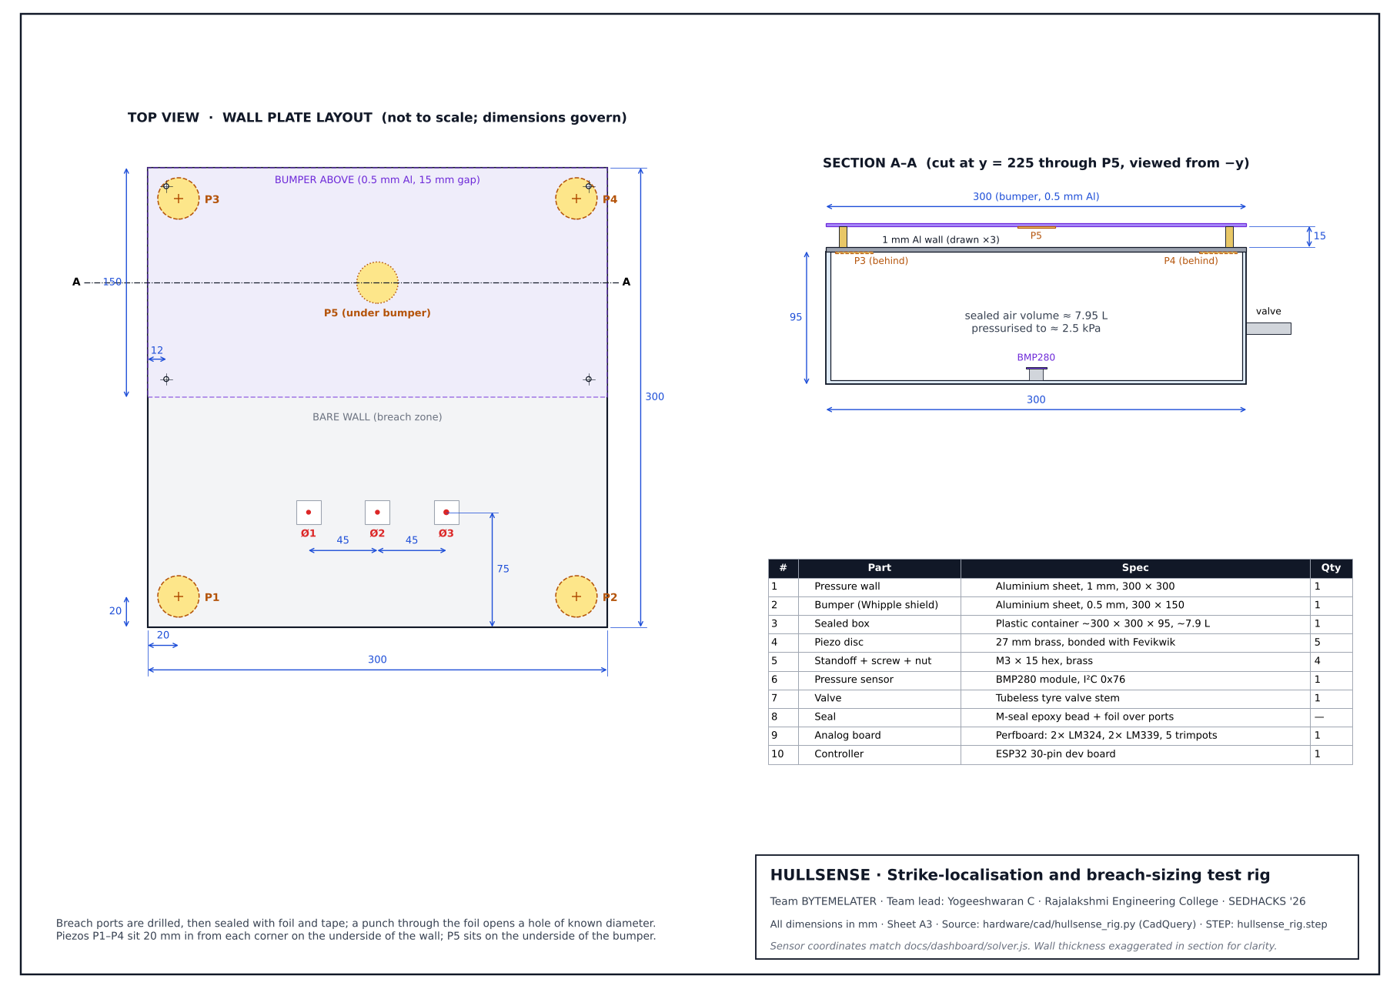
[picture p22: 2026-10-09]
hardware/cad/hullsense_rig_drawing.png

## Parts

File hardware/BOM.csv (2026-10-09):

item | qty | unit_inr | total_inr | source | price_status
ESP32 30-pin CP2102 dev board | 1 | 499 | 499 | Probots | checked Oct 2026
27 mm piezo disc (5 used + 1 spare) | 6 | 20 | 120 | Probots | checked Oct 2026
LM324 quad op-amp (band-pass x5) | 2 | 15 | 30 | Ritchie Street | estimate
LM339 quad comparator (x5) | 2 | 15 | 30 | Ritchie Street | estimate
Resistors, capacitors, 1N4148 clamps, 5 trimpots, perfboard, headers | 1 | 100 | 100 | Ritchie Street | estimate
BMP280 module (GY-BMP280) | 1 | 150 | 150 | Ritchie Street (Probots 299) | estimate
Aluminium sheet: 1 mm 300x300 wall + 0.5 mm 300x150 bumper | 1 | 250 | 250 | Ritchie Street / hardware shop | estimate
Plastic storage container ~8 L | 1 | 100 | 100 | local | estimate
M-seal epoxy putty | 1 | 60 | 60 | local | estimate
Fevikwik (bond piezos) | 2 | 10 | 20 | local | estimate
Tubeless tyre valve stem | 1 | 40 | 40 | cycle shop | estimate
M3 standoffs, screws, rubber feet | 1 | 50 | 50 | Ritchie Street | estimate
Steel balls (calibration drops) | 1 | 30 | 30 | cycle shop | estimate
TOTAL |  |  | 1479

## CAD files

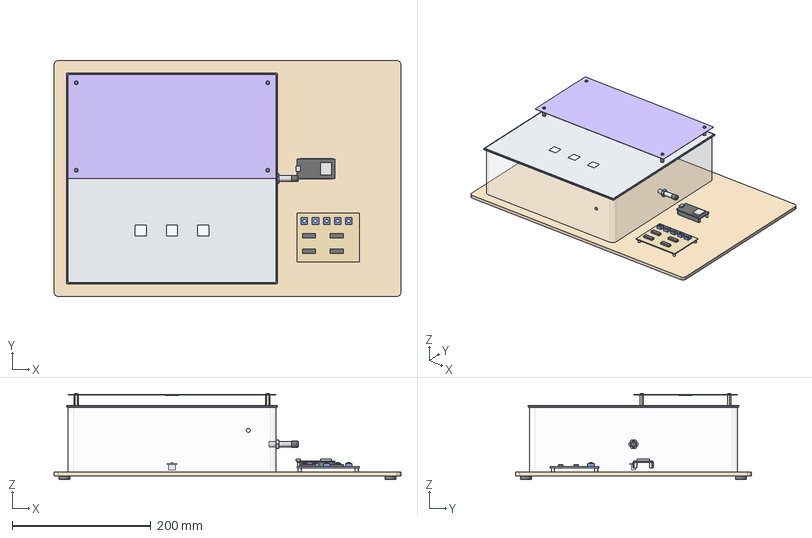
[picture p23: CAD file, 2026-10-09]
hardware/cad/hullsense_rig.step
500.0 x 340.0 x 124.3 mm
base_board
rubber_feet
sealed_box_8L
bmp280_pcb
bmp280_sensor
valve_stem
valve_cap
seal_bead_mseal
piezo_P1_P4_brass
piezo_P1_P4_ceramic
m3_nuts
wall_plate_1mm_Al
foil_patches
standoffs_M3x15
piezo_P5_brass
piezo_P5_ceramic
bumper_0p5mm_Al
m3_screws
perfboard
spacers
ic_dip14
trimpot
trimpot_screw
esp32_board
esp32_posts
esp32_module
usb_port
pin_headers

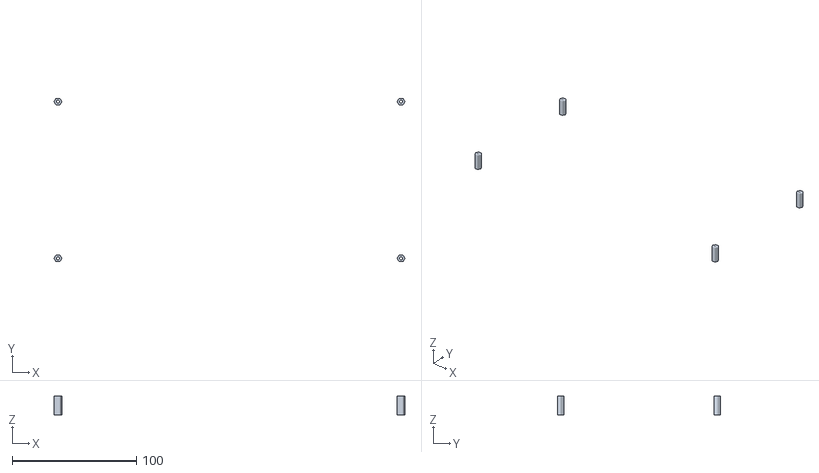
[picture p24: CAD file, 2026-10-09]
hardware/cad/stl/standoff_M3x15.stl
282.4 x 131.5 x 15.0

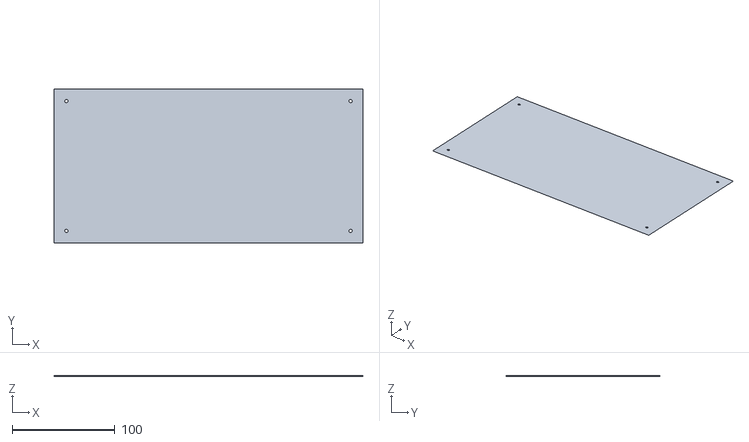
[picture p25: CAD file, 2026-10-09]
hardware/cad/stl/bumper_0p5mm_Al.stl
300.0 x 150.0 x 0.5

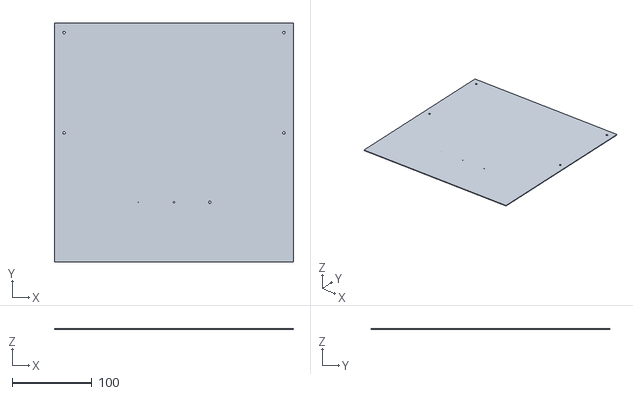
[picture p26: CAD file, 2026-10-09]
hardware/cad/stl/wall_plate_1mm_Al.stl
300.0 x 300.0 x 1.00

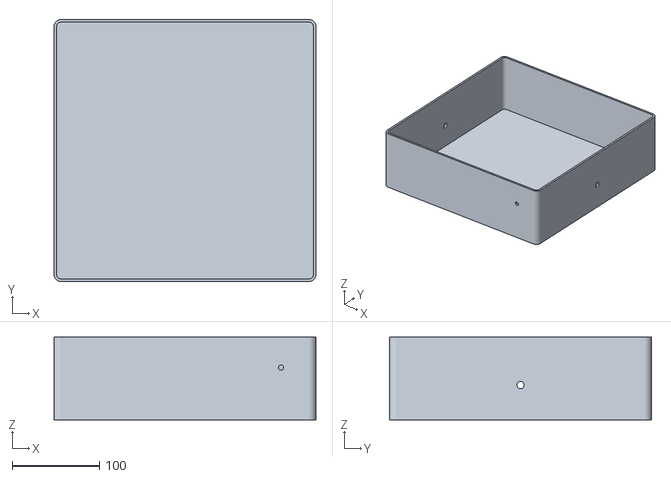
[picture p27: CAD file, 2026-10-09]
hardware/cad/stl/sealed_box_8L.stl
300.0 x 300.0 x 95.0

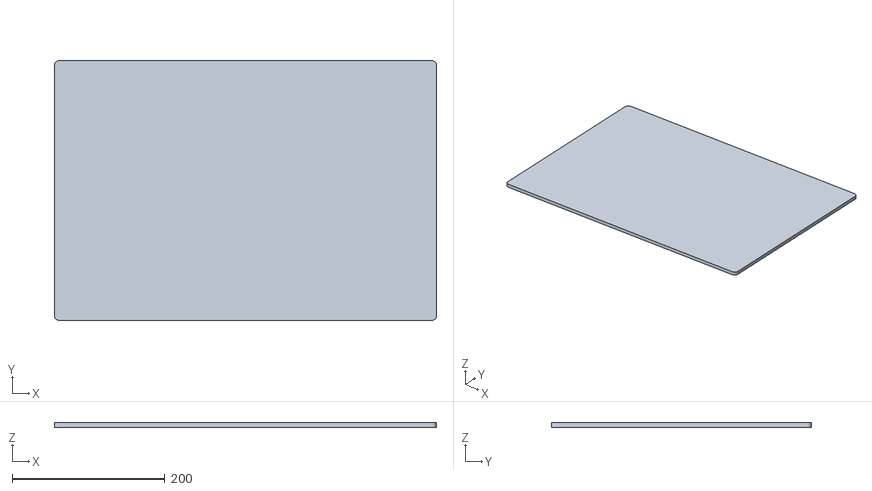
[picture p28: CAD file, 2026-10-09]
hardware/cad/stl/base_board.stl
500.0 x 340.0 x 6.00

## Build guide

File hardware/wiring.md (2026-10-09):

# Wiring and assembly

## Mechanical
1. **Wall:** 1 mm aluminium, 300 × 300 mm. It is the lid of an ~8 L plastic box, sealed all round with M-seal.
2. **Sensors:** bond four 27 mm piezo discs (brass side down) under the wall, 20 mm in from each corner, with Fevikwik. Bond the fifth disc on the bumper.
3. **Bumper:** 0.5 mm aluminium, 300 × 150 mm, on M3 standoffs 15 mm above the top half of the wall.
4. **Breach ports:** drill 1, 2 and 3 mm holes in the bare half of the wall. Seal each with kitchen foil and tape; a punch strike through the foil opens a real hole of known size.
5. **Pressure:** BMP280 inside the box; pass the four wires through a hole sealed with M-seal. A tubeless tyre valve in the box wall lets you pressurise to about 2.5 kPa with a cycle pump.

## One channel (repeat ×5)
```
piezo ─┬─ 1 MΩ to GND (bleed)
       └─ 10 kΩ ─┬─ clamp diodes to 3V3 / GND
                 └─ 10 nF ─┬─ 100 kΩ to Vref (1.65 V)
                           └─ LM324 (+), gain ≈ 11: 100 kΩ ∥ 330 pF feedback, 10 kΩ to Vref
LM324 out ─ LM339 (+);  LM339 (−) ← threshold trimpot
LM339 out ─ 10 kΩ pull-up to 3V3 ─ ESP32 capture pin
```
Vref = 3V3 divided by two 10 kΩ resistors, decoupled with 10 µF.

**Power the LM324 and LM339 from the ESP32's 5 V (VIN) pin, not 3V3.** On a 3.3 V supply the LM324 output can only rise to about 1.8 V, which leaves just 0.15 V of swing above the 1.65 V reference. On 5 V it can reach about 3.5 V. This is still safe for the ESP32: the LM339 has open-collector outputs, and its 10 kΩ pull-ups go to **3V3**, so the capture pins never see more than 3.3 V. Put a 100 nF decoupling capacitor on each IC.

Unused sections: on the spare LM324 op-amps, tie (+) to Vref and the output to (−). On the spare LM339 comparators, tie both inputs to GND.

## Pins
| Signal | GPIO |
|---|---|
| P1 / P2 / P3 / P4 (wall) | 34 / 35 / 32 / 33 |
| P5 (bumper) | 25 |
| Timer sync loop-back (leave unconnected) | 26 |
| BMP280 SDA / SCL | 21 / 22 |

## Threshold setting
With the dashboard connected, raise each trimpot until a firm desk thump next to the box does **not** trigger, then confirm a light pen tap on the wall triggers all four wall channels.

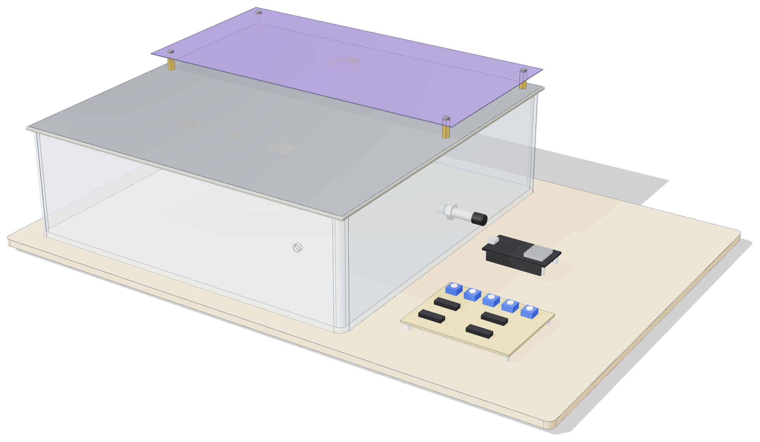
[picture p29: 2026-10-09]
docs/cad/rig_assembled.png

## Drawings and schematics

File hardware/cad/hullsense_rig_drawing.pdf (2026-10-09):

## TOP VIEW · WALL PLATE LAYOUT (not to scale; dimensions govern)

## SECTION A–A (cut at y = 225 through P5, viewed from −y)

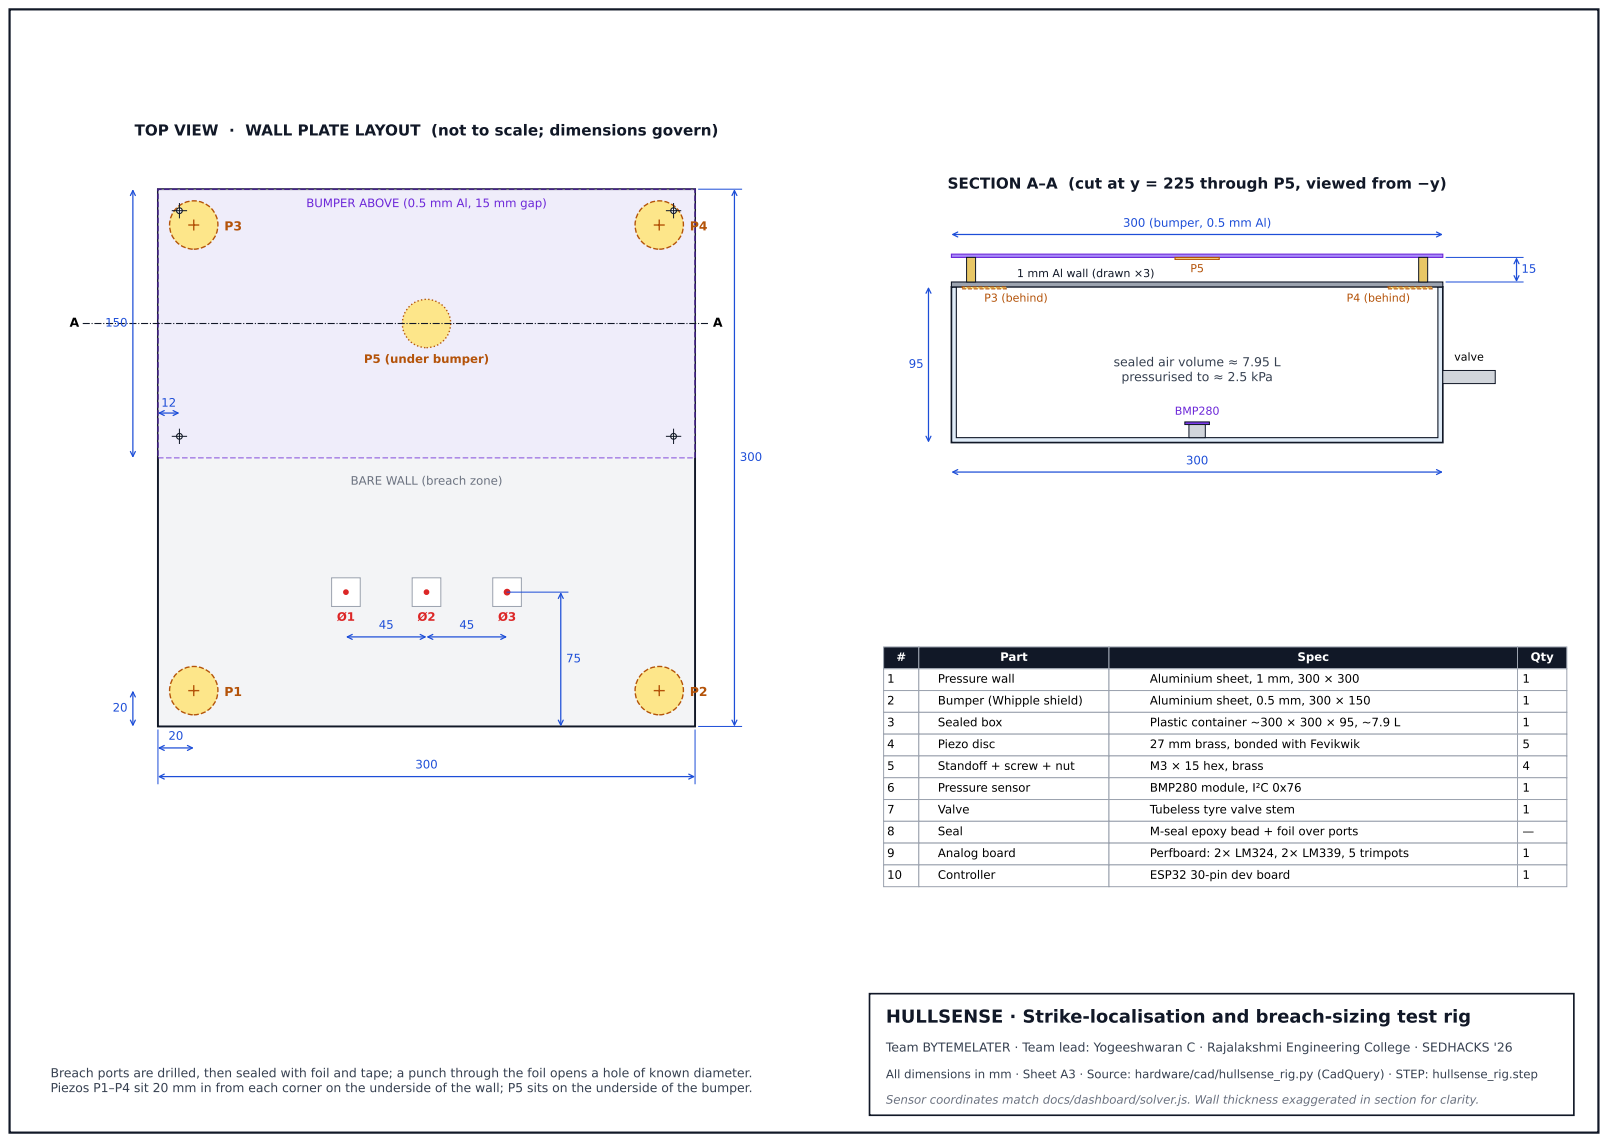
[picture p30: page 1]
P5 (under bumper); BMP280; valve; P3 (behind); P4 (behind); Part; Spec; Qty; Pressure wall; Aluminium sheet, 1 mm, 300 × 300; Bumper (Whipple shield); Aluminium sheet, 0.5 mm, 300 × 150; Sealed box; Plastic container ~300 × 300 × 95, ~7.9 L; Piezo disc; 27 mm brass, bonded with Fevikwik; Standoff + screw + nut; M3 × 15 hex, brass; Pressure sensor; BMP280 module, I²C 0x76; Valve; Tubeless tyre valve stem; Seal; M-seal epoxy bead + foil over ports; Analog board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

BUMPER ABOVE (0.5 mm Al, 15 mm gap)

300 (bumper, 0.5 mm Al)

P5 1 mm Al wall (drawn ×3)

sealed air volume ≈ 7.95 L
pressurised to ≈ 2.5 kPa

BARE WALL (breach zone)

HULLSENSE · Strike-localisation and breach-sizing test rig

Team BYTEMELATER · Team lead: Yogeeshwaran C · Rajalakshmi Engineering College · SEDHACKS '26

Breach ports are drilled, then sealed with foil and tape; a punch through the foil opens a hole of known diameter.
Piezos P1–P4 sit 20 mm in from each corner on the underside of the wall; P5 sits on the underside of the bumper.

All dimensions in mm · Sheet A3 · Source: hardware/cad/hullsense_rig.py (CadQuery) · STEP: hullsense_rig.step
Sensor coordinates match docs/dashboard/solver.js. Wall thickness exaggerated in section for clarity.

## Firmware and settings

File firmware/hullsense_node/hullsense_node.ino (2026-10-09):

// HULLSENSE sensor node firmware
// Team BYTEMELATER · SEDHACKS '26 · Rajalakshmi Engineering College
//
// What it does
//   1. Timestamps comparator edges from 5 piezo channels with the ESP32 MCPWM
//      capture hardware (12.5 ns per tick, no fast ADC needed).
//   2. Groups edges that arrive within EVENT_WINDOW_US into one "strike event" and
//      sends it as one JSON line: first rising edge (arrival) and last falling
//      edge (for time-over-threshold) per channel.
//   3. Streams box pressure from a BMP280 at ~100 Hz, so the dashboard can detect
//      and size a breach from the pressure decay.
//   4. Sends a heartbeat with per-channel edge counters, so a dead sensor is
//      reported as a fault instead of being read as "all clear".
//
// Board:   ESP32 DevKit V1 (classic ESP32, 30-pin)
// Core:    Arduino-ESP32 3.x (built on ESP-IDF 5.x, which provides driver/mcpwm_cap.h)
// Library: Adafruit BMP280 (install via Library Manager)
//
// Serial protocol (921600 baud, one JSON object per line)
//   {"t":"evt","id":12,"us":123456,"rise":[r1,r2,r3,r4,r5],"fall":[f1,...],"n":[e1,...]}
//       rise/fall are capture-timer ticks (uint32, 80 MHz); 0 means "no edge".
//   {"t":"p","us":123456,"pa":101412.37}
//   {"t":"hb","us":...,"edges":[...],"sync":1,"bmp":1}
// Commands from the dashboard: "SYNC\n" re-aligns the timers, "PING\n" -> {"t":"pong"}

#include <Arduino.h>
#include <Wire.h>
#include <Adafruit_BMP280.h>
#include "driver/mcpwm_cap.h"
#include "driver/mcpwm_sync.h"
#include "driver/gpio.h"
#include "esp_timer.h"
#include "config.h"

static const int NCH = 5;
static const int CAP_PINS[NCH] = {PIN_P1, PIN_P2, PIN_P3, PIN_P4, PIN_P5};
static const int CAP_GROUP[NCH] = {0, 0, 0, 1, 1};

static mcpwm_cap_timer_handle_t capTimer[2] = {nullptr, nullptr};
static mcpwm_cap_channel_handle_t capChan[NCH] = {nullptr};
static mcpwm_sync_handle_t syncSrc[2] = {nullptr, nullptr};
static bool syncOk = false;

// ---- shared between ISR and loop ----
static portMUX_TYPE evMux = portMUX_INITIALIZER_UNLOCKED;
static volatile uint32_t evRise[NCH];
static volatile uint32_t evFall[NCH];
static volatile uint16_t evEdges[NCH];
static volatile bool evActive = false;
static volatile int64_t evStartUs = 0;
static volatile int64_t holdoffUntilUs = 0;
static volatile uint32_t totalEdges[NCH];

static Adafruit_BMP280 bmp;
static bool bmpOk = false;
static uint32_t eventId = 0;

// ---------------------------------------------------------------------------
// Capture ISR: keep the FIRST rising edge (arrival) and the LAST falling edge
// (end of the burst) for each channel during the event window.
// ---------------------------------------------------------------------------
static bool IRAM_ATTR onCapture(mcpwm_cap_channel_handle_t chan, const mcpwm_capture_event_data_t *ed, void *user) {
  const int ch = (int)(intptr_t)user;
  const int64_t now = esp_timer_get_time();
  portENTER_CRITICAL_ISR(&evMux);
  totalEdges[ch]++;
  if (now >= holdoffUntilUs) {
    if (ed->cap_edge == MCPWM_CAP_EDGE_POS) {
      if (!evActive) {               // first edge of a new event
        evActive = true;
        evStartUs = now;
        for (int i = 0; i < NCH; i++) { evRise[i] = 0; evFall[i] = 0; evEdges[i] = 0; }
      }
      if (evRise[ch] == 0) evRise[ch] = ed->cap_value ? ed->cap_value : 1;
    } else if (evActive) {
      evFall[ch] = ed->cap_value ? ed->cap_value : 1;
    }
    if (evActive) evEdges[ch]++;
  }
  portEXIT_CRITICAL_ISR(&evMux);
  return false;  // no task to wake
}

// ---------------------------------------------------------------------------
// Phase-align both capture timers: one GPIO, looped back into both MCPWM groups.
// If anything here fails, the dashboard's 5-tap calibration still absorbs the
// constant offset between the two groups (both count the same APB clock).
// ---------------------------------------------------------------------------
static void pulseSync() {
  gpio_set_level((gpio_num_t)PIN_SYNC, 1);
  delayMicroseconds(5);
  gpio_set_level((gpio_num_t)PIN_SYNC, 0);
}

static void setupSync() {
  esp_err_t err = ESP_OK;
  for (int g = 0; g < 2 && err == ESP_OK; g++) {
    mcpwm_gpio_sync_src_config_t sc = {};
    sc.group_id = g;
    sc.gpio_num = PIN_SYNC;
    sc.flags.io_loop_back = true;   // we drive this pin ourselves
    sc.flags.pull_down = true;
    err = mcpwm_new_gpio_sync_src(&sc, &syncSrc[g]);
    if (err != ESP_OK) break;
    mcpwm_capture_timer_sync_phase_config_t ph = {};
    ph.sync_src = syncSrc[g];
    ph.count_value = 0;
    ph.direction = MCPWM_TIMER_DIRECTION_UP;
    err = mcpwm_capture_timer_set_phase_on_sync(capTimer[g], &ph);
  }
  if (err == ESP_OK) {
    gpio_set_direction((gpio_num_t)PIN_SYNC, GPIO_MODE_INPUT_OUTPUT);
    gpio_set_level((gpio_num_t)PIN_SYNC, 0);
    pulseSync();
    syncOk = true;
  } else {
    Serial.printf("{\"t\":\"warn\",\"msg\":\"timer sync unavailable (%s); calibration will absorb the offset\"}\n", esp_err_to_name(err));
  }
}

static void setupCapture() {
  for (int g = 0; g < 2; g++) {
    mcpwm_capture_timer_config_t tc = {};
    tc.group_id = g;
    tc.clk_src = MCPWM_CAPTURE_CLK_SRC_DEFAULT;  // APB 80 MHz on ESP32
    ESP_ERROR_CHECK(mcpwm_new_capture_timer(&tc, &capTimer[g]));
  }
  for (int ch = 0; ch < NCH; ch++) {
    mcpwm_capture_channel_config_t cc = {};
    cc.gpio_num = CAP_PINS[ch];
    cc.prescale = 1;
    cc.flags.pos_edge = true;
    cc.flags.neg_edge = true;
    cc.flags.pull_up = false;   // external 10k pull-up on each LM339 output
    ESP_ERROR_CHECK(mcpwm_new_capture_channel(capTimer[CAP_GROUP[ch]], &cc, &capChan[ch]));
    mcpwm_capture_event_callbacks_t cbs = {};
    cbs.on_cap = onCapture;
    ESP_ERROR_CHECK(mcpwm_capture_channel_register_event_callbacks(capChan[ch], &cbs, (void *)(intptr_t)ch));
    ESP_ERROR_CHECK(mcpwm_capture_channel_enable(capChan[ch]));
  }
  for (int g = 0; g < 2; g++) {
    ESP_ERROR_CHECK(mcpwm_capture_timer_enable(capTimer[g]));
    ESP_ERROR_CHECK(mcpwm_capture_timer_start(capTimer[g]));
  }
  setupSync();
}

static void setupPressure() {
  Wire.begin(PIN_SDA, PIN_SCL, 400000);
  bmpOk = bmp.begin(BMP280_ADDR);
  if (!bmpOk) {
    Serial.println("{\"t\":\"warn\",\"msg\":\"BMP280 not found\"}");
    return;
  }
  // Fast, unfiltered pressure: a breach drains the box in 1 to 11 s, so speed beats smoothing.
  bmp.setSampling(Adafruit_BMP280::MODE_NORMAL,
                  Adafruit_BMP280::SAMPLING_X1,    // temperature
                  Adafruit_BMP280::SAMPLING_X2,    // pressure
                  Adafruit_BMP280::FILTER_OFF,
                  Adafruit_BMP280::STANDBY_MS_1);
}

static void emitEventIfReady() {
  if (!evActive) return;
  const int64_t now = esp_timer_get_time();
  if (now - evStartUs < EVENT_WINDOW_US) return;

  uint32_t rise[NCH], fall[NCH];
  uint16_t edges[NCH];
  int64_t startUs;
  portENTER_CRITICAL(&evMux);
  for (int i = 0; i < NCH; i++) { rise[i] = evRise[i]; fall[i] = evFall[i]; edges[i] = evEdges[i]; }
  startUs = evStartUs;
  evActive = false;
  holdoffUntilUs = now + HOLDOFF_US;
  portEXIT_CRITICAL(&evMux);

  eventId++;
  Serial.printf("{\"t\":\"evt\",\"id\":%lu,\"us\":%lld,\"rise\":[%lu,%lu,%lu,%lu,%lu],\"fall\":[%lu,%lu,%lu,%lu,%lu],\"n\":[%u,%u,%u,%u,%u]}\n",
                (unsigned long)eventId, (long long)startUs,
                (unsigned long)rise[0], (unsigned long)rise[1], (unsigned long)rise[2], (unsigned long)rise[3], (unsigned long)rise[4],
                (unsigned long)fall[0], (unsigned long)fall[1], (unsigned long)fall[2], (unsigned long)fall[3], (unsigned long)fall[4],
                edges[0], edges[1], edges[2], edges[3], edges[4]);
}

static void handleCommands() {
  static char buf[32];
  static uint8_t len = 0;
  while (Serial.available()) {
    char c = (char)Serial.read();
    if (c == '\n' || c == '\r') {
      buf[len] = 0;
      if (!strcmp(buf, "SYNC") && syncOk) { pulseSync(); Serial.println("{\"t\":\"ack\",\"cmd\":\"SYNC\"}"); }
      else if (!strcmp(buf, "PING")) Serial.println("{\"t\":\"pong\"}");
      len = 0;
    } else if (len < sizeof(buf) - 1) {
      buf[len++] = c;
    }
  }
}

void setup() {
  Serial.begin(SERIAL_BAUD);
  delay(200);
  setupCapture();
  setupPressure();
  Serial.printf("{\"t\":\"hello\",\"fw\":\"hullsense-node 1.0\",\"tick_hz\":%lu,\"sync\":%d,\"bmp\":%d}\n",
                (unsigned long)CAPTURE_TICK_HZ, syncOk ? 1 : 0, bmpOk ? 1 : 0);
}

void loop() {
  static uint32_t lastP = 0, lastHb = 0;
  const uint32_t ms = millis();

  emitEventIfReady();
  handleCommands();

  if (bmpOk && ms - lastP >= PRESSURE_PERIOD_MS) {
    lastP = ms;
    const float pa = bmp.readPressure();
    Serial.printf("{\"t\":\"p\",\"us\":%lld,\"pa\":%.2f}\n", (long long)esp_timer_get_time(), pa);
  }

  if (ms - lastHb >= HEARTBEAT_MS) {
    lastHb = ms;
    uint32_t e[NCH];
    portENTER_CRITICAL(&evMux);
    for (int i = 0; i < NCH; i++) e[i] = totalEdges[i];
    portEXIT_CRITICAL(&evMux);
    Serial.printf("{\"t\":\"hb\",\"us\":%lld,\"edges\":[%lu,%lu,%lu,%lu,%lu],\"sync\":%d,\"bmp\":%d}\n",
                  (long long)esp_timer_get_time(),
                  (unsigned long)e[0], (unsigned long)e[1], (unsigned long)e[2], (unsigned long)e[3], (unsigned long)e[4],
                  syncOk ? 1 : 0, bmpOk ? 1 : 0);
  }
}

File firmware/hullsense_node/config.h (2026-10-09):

// HULLSENSE node configuration
// Team BYTEMELATER · SEDHACKS '26
#pragma once

// ---------------- Capture inputs (LM339 outputs, 10k pull-up to 3V3) ----------------
// An LM339 output goes HIGH when the band-passed piezo signal crosses its threshold,
// so the rising edge is the arrival time and the falling edge ends the burst.
//
// The ESP32 has 2 MCPWM groups x 3 capture channels. P1..P3 use group 0, P4 and the
// bumper sensor P5 use group 1. Both capture timers count the 80 MHz APB clock
// (12.5 ns per tick) and are phase-aligned at boot with a GPIO sync pulse.
#define PIN_P1 34   // wall, corner (20, 20) mm
#define PIN_P2 35   // wall, corner (280, 20) mm
#define PIN_P3 32   // wall, corner (20, 280) mm
#define PIN_P4 33   // wall, corner (280, 280) mm
#define PIN_P5 25   // bumper (outer shield), centre of bumper sheet

#define PIN_SYNC 26 // spare GPIO, driven internally to phase-align both capture timers

// ---------------- BMP280 (I2C) ----------------
#define PIN_SDA 21
#define PIN_SCL 22
#define BMP280_ADDR 0x76         // 0x77 on some boards (SDO high)
#define PRESSURE_PERIOD_MS 10    // ~100 samples per second

// ---------------- Event logic ----------------
#define CAPTURE_TICK_HZ 80000000UL // APB clock on the classic ESP32
#define EVENT_WINDOW_US 2000       // collect edges for 2 ms after the first rising edge
#define HOLDOFF_US 30000           // ignore ringing for 30 ms after an event
#define HEARTBEAT_MS 1000

#define SERIAL_BAUD 921600

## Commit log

2026-10-09 HULLSENSE: firmware, dashboard, docs site, hardware notes, model and tests
    ESP32 firmware (MCPWM capture at 12.5 ns, BMP280 pressure, heartbeat),
    Web Serial dashboard with calibration, localisation, triage and breach sizing,
    build brief served from docs/ via GitHub Pages.
    Claude-Session: https://claude.ai/code/session_016FykkTtZMrmPMksY2ocxgM
    [BOM.csv]
2026-10-09 Link case studies to their sources in deck and docs
    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
2026-10-09 Add parametric CAD model of the test rig
    CadQuery model with STEP assembly, GLB (assembled and exploded), STL parts,
    A3 dimensioned drawing and renders; interactive 3D viewer at docs/cad/.
    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
    [base_board.stl, bumper_0p5mm_Al.stl, hullsense_rig.step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]
2026-10-09 Deck: CAD renders and CAD link
    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
2026-10-09 Wiring: power op-amps from 5 V for output swing; add Cirkit Designer prompt
    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
2026-10-11 Add itemised shopping list checked against wiring and firmware
    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
2026-10-12 Dashboard: config, accuracy/tests, record-replay, debug, demo mode, incident report
    - config.js holds all rig numbers; Setup panel and calibration persist in localStorage
    - Accuracy test (grid and free mode) with CSV and summary
    - Guided tests: shield vs wall, noise, soft vs hard, combined results box
    - Record and replay of sessions with a clear REPLAY banner
    - Debug panel: event timing, edge rates, channel check, raw console, BMP status
    - Demo mode for the projector with voice alerts and a last-10 heatmap
    - Optional OpenRouter incident report with a local template fallback
2026-10-12 Dashboard: direct-mode live signal card, threshold control, peak column
    - Live signal card (real ADC values): 5 bars with threshold marker, decay after 1 s, timing step from hb
    - DIRECT MODE badge from hello/hb mode; threshold "TH <n>" through the shared serial writer, ack shown
    - Debug: peak (V) column when events carry pk; hide live-level lines checkbox
    - lv lines record and replay like any other; simulation never shows the card
    - solver, calibration, triage, tests, config unchanged
2026-10-12 Hide the Simulation button and rename Demo mode to Projector view
